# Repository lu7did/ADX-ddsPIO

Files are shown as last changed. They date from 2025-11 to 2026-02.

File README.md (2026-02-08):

# ADX-ddsPIO

A brief story of the project start with the excelent ADX Transceiver from Barb (WB2CBA) which can be found at

* Github site [link](http://www.github.com/WB2CBA/ADX).
* ADX transceiver blog [link](https://antrak.org.tr/blog/adx-arduino-digital-transceiver)

The ADX transceiver is powered by an Arduino Nano (ADX) or Arduino Uno (ADX_UNO) boards using both the 
ATMEL ATMEGA382p processor.

In order to leverage the capabilities of the transceiver with a powerful processor such as the Raspberry Pi Pico
which uses the rp2040 architecture a project called **ADX-rp2040** was started.

Then a map between the Arduino board I/O and the rp2040 I/O was made showing some differences needs to be addressed
which requires additional circuitry.

As an evolution of that project the goal to reduce the footprint of the transceiver, trying to remove the 
signal generator function (Si5351 based), this effort leads to this project.

The project aims to achiveve several (experimental) goals:

* Port the ADX firmware to the rp2040 (already done with the [ADX-rp2040](https://www.github.com/lu7did/ADX-rp2040)
* Design and develop a hardware board to support the project
* Implement a USB digital audio interface, the board can be seen as a virtual sound card.
* Implement an all Raspberry Pico based DDS generation (no Si5351 board).

Once implemented an ADX class FT8 digital transceiver can be created using
different hardware strategies.

Basic specs for this transceiver would be:

* Operate in any of the HF bands (160m to 10m), attempts to marginal use on 6m will be made.
* 2-3W output (WSPR,FT8;JS8,FT4).
* Different alternatives for receiver:
	*  DC (CD2003GP).
	*  Ssuperhet (CD20023GP)
	*  Digital (Si4732 based)
* SWR protection.
* Beacon mode (WSPR,FT8).
* ATU reset output.
* PA SWR protection (zener diode).

This project relies *heavily* on the superb work made by several authors:

* Roman (R2BDT) with his pico-WSPR-tx project (link) which in turns relies on his pico-hf-oscillator project
  [link](https://github.com/RPiks/pico-hf-oscillator)

* Hitoshi-san (JE1RAV) with his QP-7C_RP2040 project did most of the heavy lifting to use a USB for both
  digital audio and serial interface (CDC).
  [link](https://github.com/je1rav/QP-7C_RP2040).

* As said the ADX architecture has been originally developed and promoted by Barb 
  (WB2CBA) and had been spinned off by dozens of experimental implementations, most
  of the transceiver hardware is rooted on his signature original design.

* The ADX-rp2040 firmware was originally developed by me as an adaptation of the ADX Arduino firmware,
  differences with the original code were quite large so the actual final code was refactored in the process.
  [link](https://github.com/lu7did/ADX-rp2040)

* An early effort called RDX-rp2040 was originally developed as a stand alone FT8 transceiver able to
  operate without a PC, the project reach the prototype stage and stays there since. Part of the hardware
  and the si4732 utilization comes out of it,  not being an optimal implementation the board designed
  for that project can also be reused.
  [link](https://github.com/lu7did/RDX-rp2040)

* Hans Summers (G0UPL) developed the original QCX transceiver, which creates a whole
  family of high performance, yet affordable,  homebrew transceivers.

* Guido (PE1NNZ) who developed the original uSDX microcode for the Arduino which inspired
  manyfold designs, specially the uSDX class transceivers, and opened the gate for a generation
  of low cost at reasonable performance ham radio equipment.
 
With enough luck and cooperation this project might turn into a system which
includes the different components in order to be reproduced, lots of work needs
to occur for this to happen.

73 de Pedro (LU7DZ/LT7D)

# Support and issues

This is an experimental, work-in-progress, non-profit project performed as closest to the ham spirit as possible. Only spare, hobby,
time is available to move the project forward or to provide support on usage or issues.

Until further notice is provided this project is **work in progress** and not able to be reproduced directly.

If anybody has questions or issues please:
 
* Be sure you read the documentation first.
* Check on the issues list of the GitHub site, the issue might have been described there or even a workaround might exists for it.
* State it as an  English request. English isn’t even my fourth language, still I do my best to adhere to it. 
* For casual question you can use the groups.io uSDX forum and for a longer ones please open and issue at the GitHub portal of the project. 
* Express very clearly which version and level the firmware has. In most cases using the latest would solve the issue.
* Ensure the issue happens with a freshly downloaded last version of the firmware, don’t expect me to debug any modification you did.
* Describe in your own words the problem and what you did to expose it and what workarounds you attempted.
* Add the content of the monitoring terminal session with DEBUG enabled to help me understand what is going on.
* Attach any other documentation you think might help debugging the issue.

Please report ONE (1) issue per entry, and proceed as clean as possible with the debug instructions given to you to further understand or to fix the problem. 
I’ll address your issue as soon as my available time allows, not necessarily in a FIFO way.

# ADX-ddsPIO Firmware

## Architecture

The overall program architecture can be seen in the following activity graph
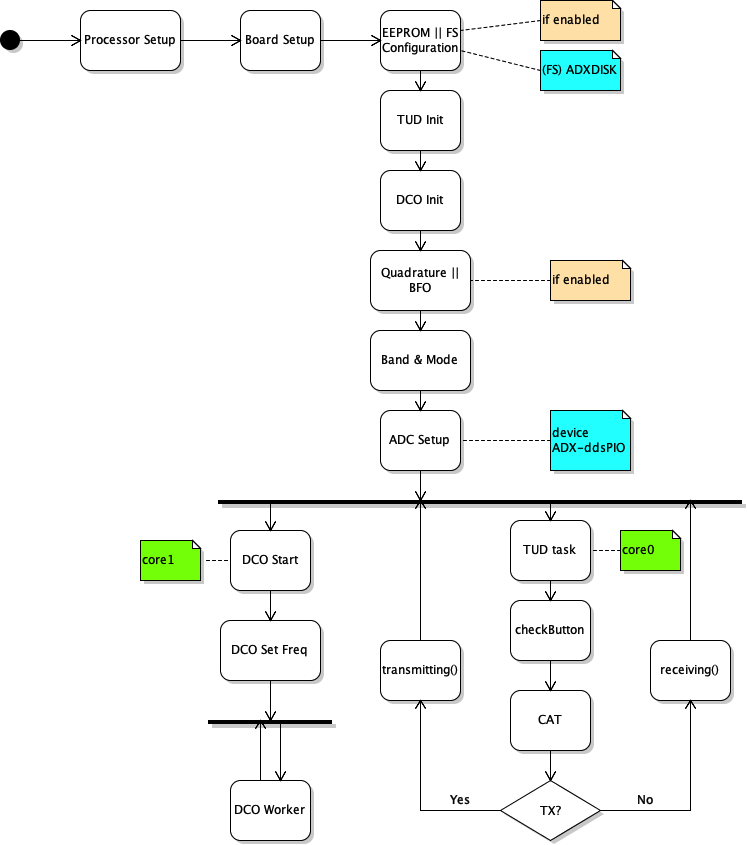
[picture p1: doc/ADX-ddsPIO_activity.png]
ADX-ddsPIO Architecture


The main Transmit-Receive cycle loop can be seen in the following activity graph
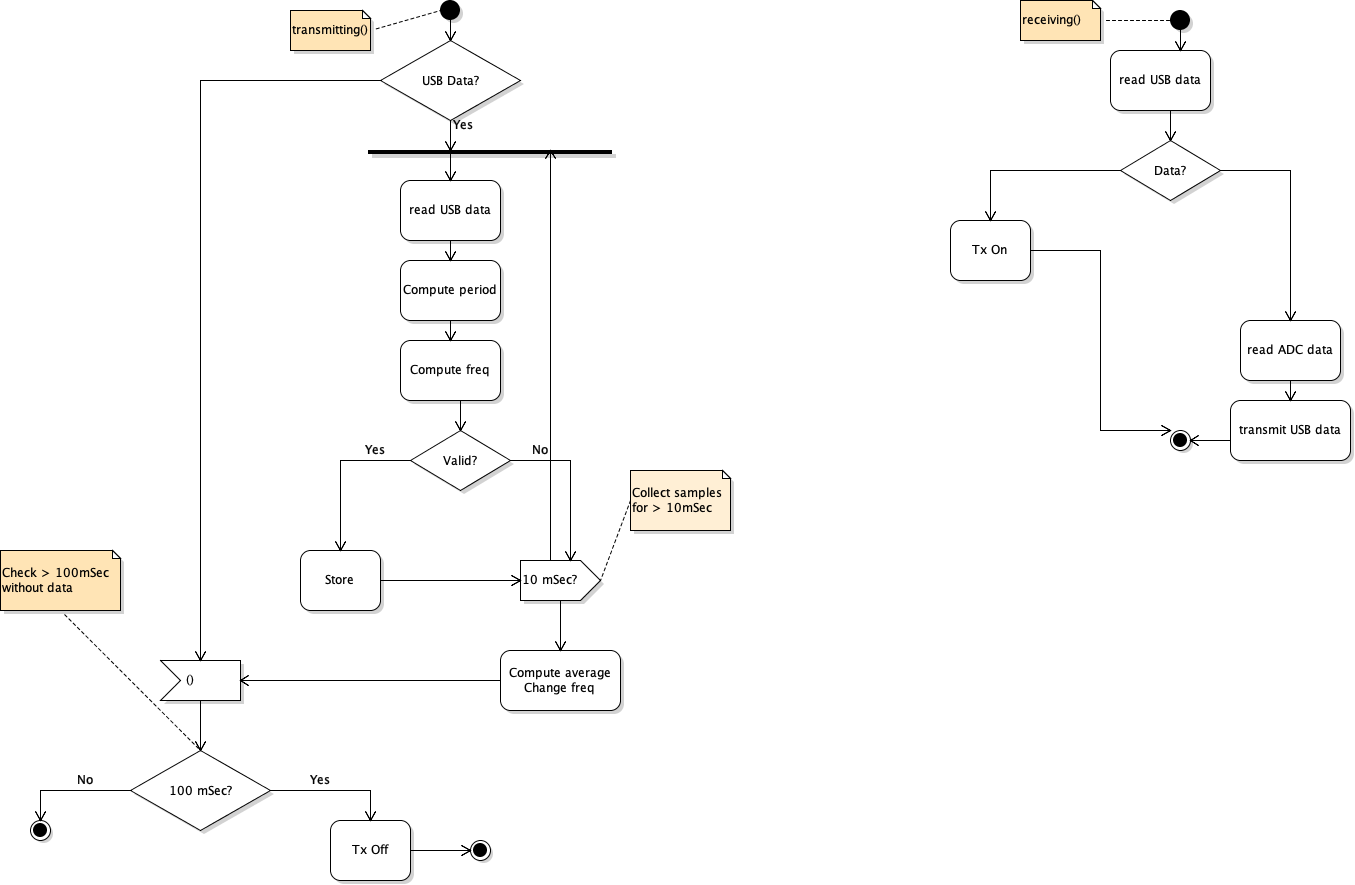
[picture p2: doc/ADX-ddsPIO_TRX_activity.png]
ADX-ddsPIO TRX cycle


## ADX-ddsPIO Firmware (Version 1.0) 

This is the first version of the firmware, the main functions implemented
are:

* Operate in any of the HF bands (160m to 10m), attempts to marginal use on 6m will be made.
* 1W RF power, DC receiver (CD2003GP based) with SWR protection.
* Management of the ADX-ddsPIO board.
* Receive and transmit digital audio data over a USB connection.
* Is able to operate with weak mode signals.

The firmware is completed at this stage and able to sustain QSO as shown in the following picture
where a contact is been made between the board (dubbed as LU2EIC) and my 20m digital FT8 station
running as LU7DZ using a direct conversion receiver setup.
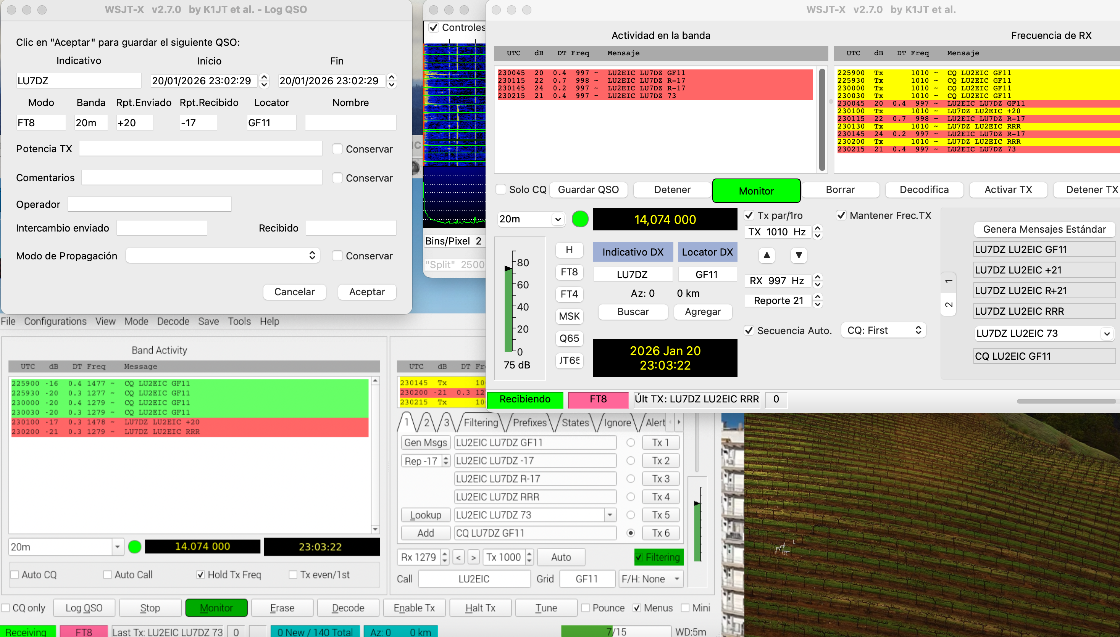
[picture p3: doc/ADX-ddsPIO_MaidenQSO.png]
ADX-ddsPIO Maiden QSO

Although the RF setup is close to trivial, just few meters distance, the activity has been held
"over the air" and shows the firmware is able to properly encode and decode signals both at the
audio and RF levels. My 20m station is composed of a QDX transceiver being run by a Raspberry Pi
controller running a modified version of WSJT-Z whilst the testbed for the ADX-ddsPIO is my
Mac running the MacOS version of WSJTX. For all practical purposes this is considered the 
"maiden QSO" of the board and all goals for this level can be called as completed.

## ADX-ddsPIO Firmware (Version 1.1)

Features

* Permanent settings (EEPROM emulation).
* CAT control (TS2000 emulation).

## ADX-ddsPIO Firmware (Version 1.2)

* Superhet ADX-S support.
* Implementation of a BFO (465 KHz) local oscillator.

## ADX-ddsPIO Firmware (Version 1.3)

* Quadrature based receiver (SDR) support (quadrature clock available)

## ADX-ddsPIO Firmware (Version 2.0)

* Si4732 based receiver chipset support
* USB (MSC) drive filesystem implementation to store external configuration (CONFIG.SYS) 

The firmware is completed at this stage and able to sustain QSO as shown in the following picture
where a contact is been made between the board (dubbed as LU2EIC) and my 20m digital FT8 station
running as LU7DZ using the Si4732 chip as a receiver.
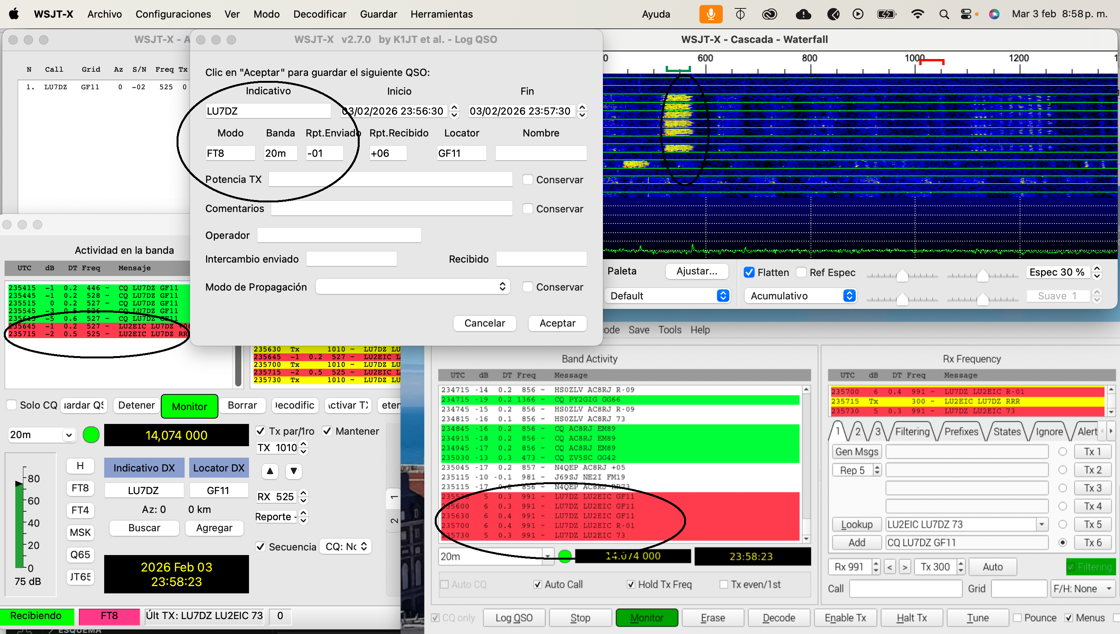
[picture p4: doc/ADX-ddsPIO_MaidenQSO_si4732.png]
ADX-ddsPIO Maiden QSO


## Build environment

The development environment used is Visual Studio code using the standard Raspberry Pi Pico C/C++ SDK.

Please follow the official documentation of both to install and configure the functionality.

## Flashing the firmware

The firmware could be flashed directly to the Raspberry Pi Pico (rp2040) processor on the
board following the conventional BOOTSEL method.

The file to flash is *./src/build/ADX-ddsPIO.uf2* .

# Hardware

I started the porting of the firmware assuming an ADX transceiver board, no more but no less features, but being powered
by a Raspberry Pico board; the porting of the software was a great deal of a learning curve not only for the rp2040
architecture being different from the ATMEGA382p and being more powerful, but also a substantially different build chain
which in some cases is implementing partially some features. For migration purposed the Raspberry Pi Pico board was used.

## Board support

At his point the Raspberry Pi Pico (standard) and the RP2040 Zero boards are *supported*.

The Raspberry Pi Pico W (wireless) is **not supported**.

## Circuit Design Si4732 based Receiver (version 2.x)

This circuit is largely based on the former RDX_rp2040 project design and it's compatible
with that board design with just minor mods.
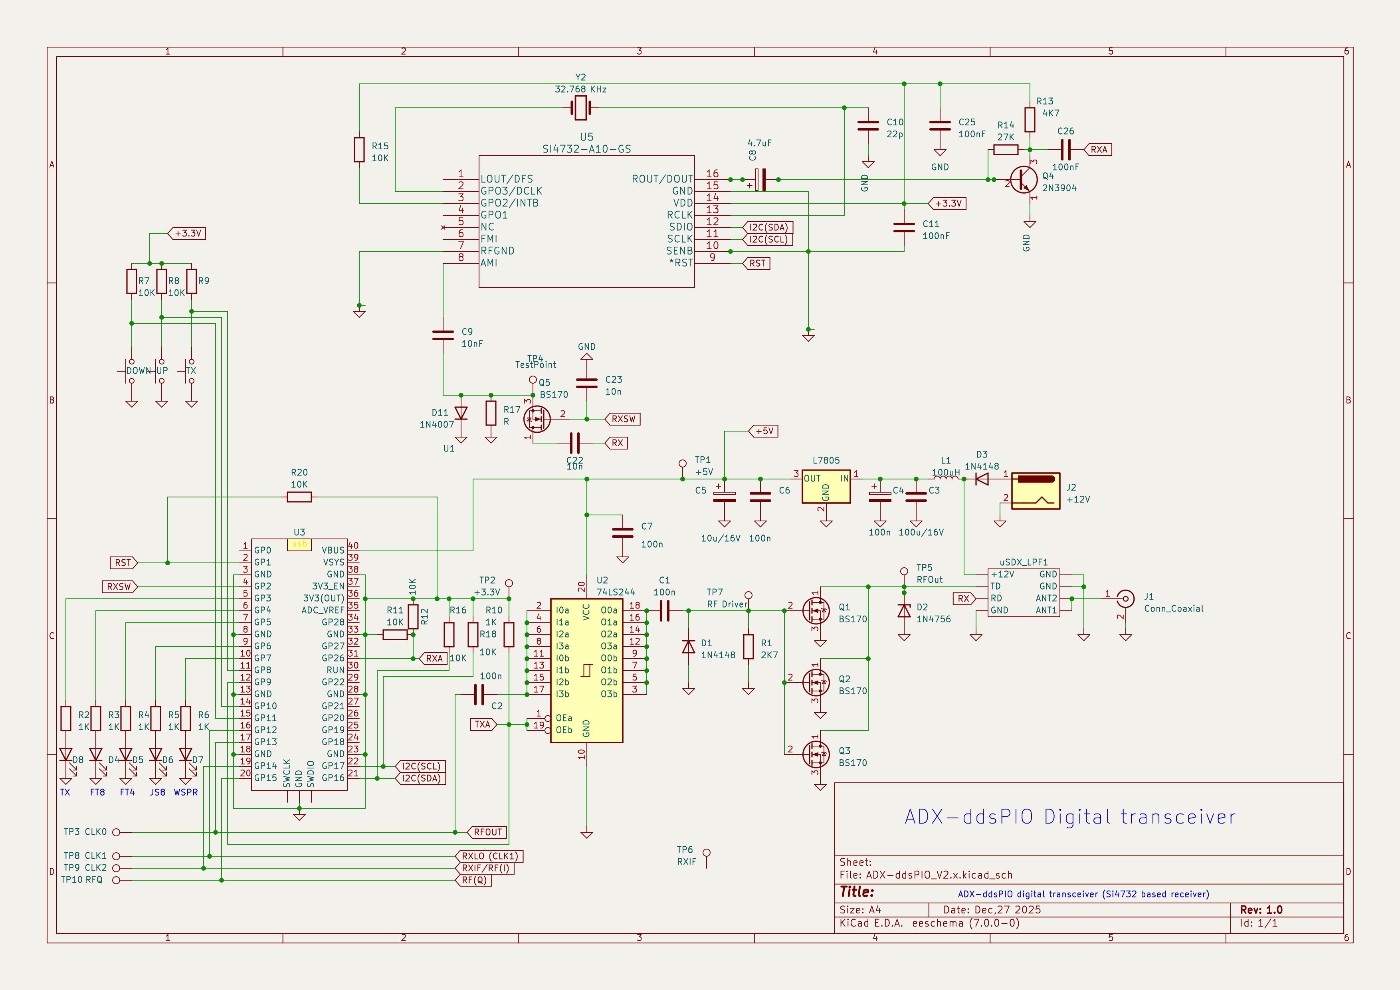
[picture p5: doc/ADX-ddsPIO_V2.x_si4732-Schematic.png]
Transceiver Circuit (Version 2.x)


The main differences with the verion 1.x:

* The receiver configuration has been changed to use the Si4732 receiver chipset.

A new, fresh, board design will eventually be made, however the development is supported with 
a prototype based on a modified RDX_rp2040 board.

### Modifications to adapt RDX board to ADX-ddsPIO

Modifications could be made to the RDX board to operate with firmware level 2.x or up
main advantage at this point is the availability of a PCB design which allows the usage
of SMD components easily.

The required mods for the RDX board to work with the ADX-ddsPIO firmware are:

* Cut the PCB wire PICO ADC0 (GPIO26) to R10/R11/C10.
* Run a wire  from R10/R11/C10 to PICO ADC2 (GPIO28).
* Run 2 pullup 10K resistors from PICO GPIO16 to +3.3V and GPIO17 to +3.3V.
* Do not use a Si5351 breakout board
* Run a wire from GPIO13 to the CLK0 pin of the Si5351 place.
* Run a 10K pullup resistor from Si4732 pin 3 (INTB) to +3.3V.
* If running with an external +12V cc supply remove jumper J7.
  
```
Work in progress
```

## Circuit Design Superhet Receiver (version 1.x)

This circuit is largely based on the ADX transceiver modification made by Hitoshi Kawaji (JE1RAV) and
marketed as a kit form by Adam Rong (BD6CR) at CRKits.com ([link](http://crkits.com/) ).
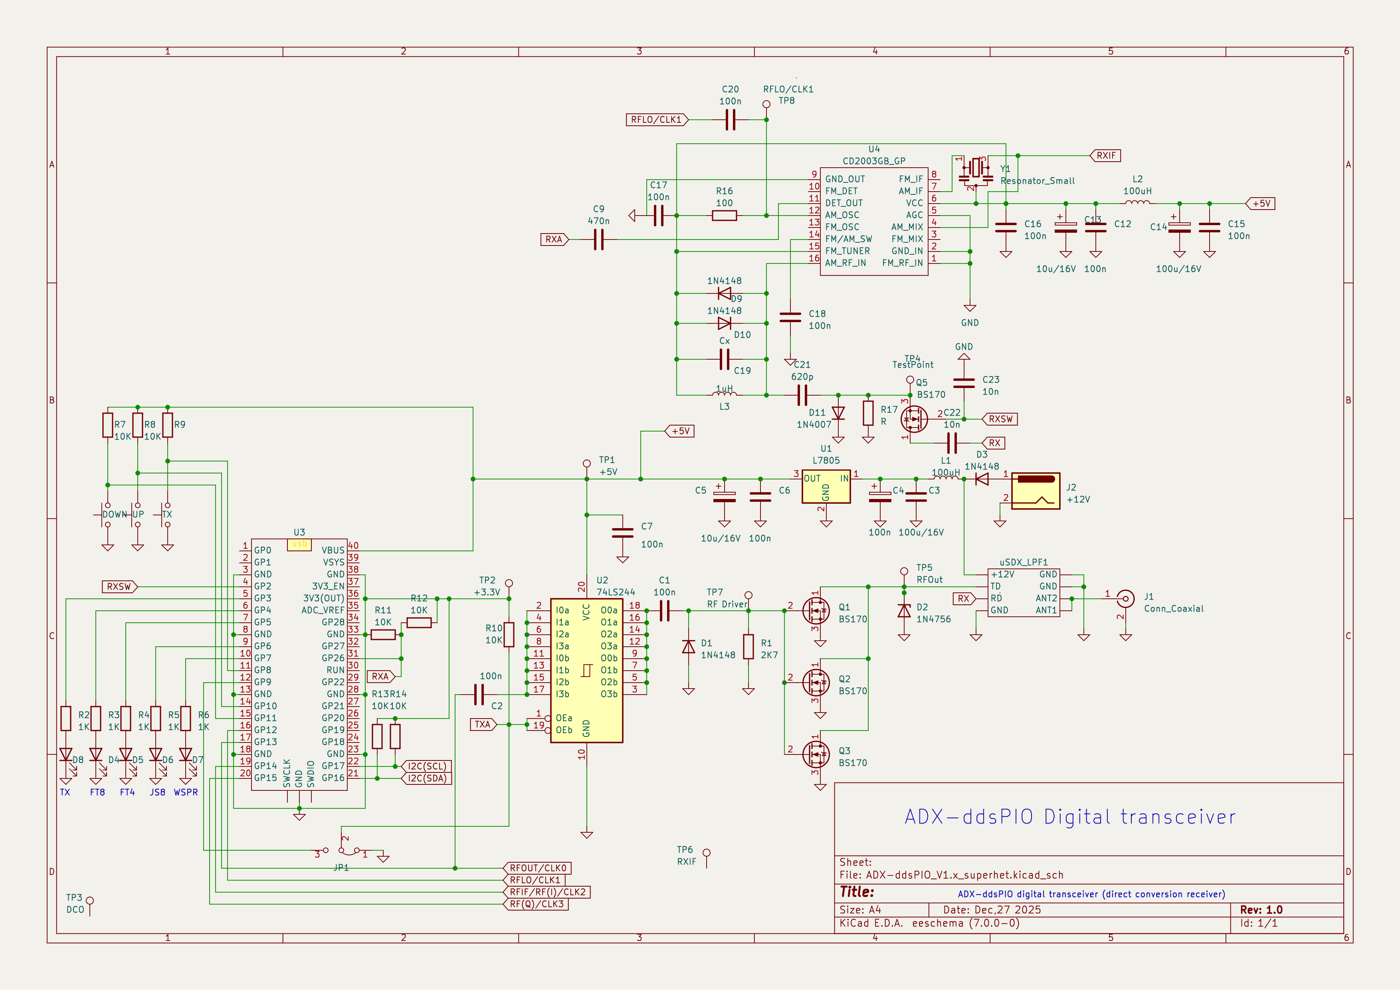
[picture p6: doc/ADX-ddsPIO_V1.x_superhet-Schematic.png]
Transceiver Circuit (Version 1.x)


The main differences with the verion 0.x:

* The receiver configuration has been changed to a superhet.

## Circuit Design Direct Conversion Receiver (version 1.x)

This circuit is largely based on the original ADX transceiver [link](https://github.com/WB2CBA/ADX) by Barb ([WB2CBA](https://www.qrz.com/db/WB2CBA))
modified for the rp2040 processor at the ADX-rp2040 project.
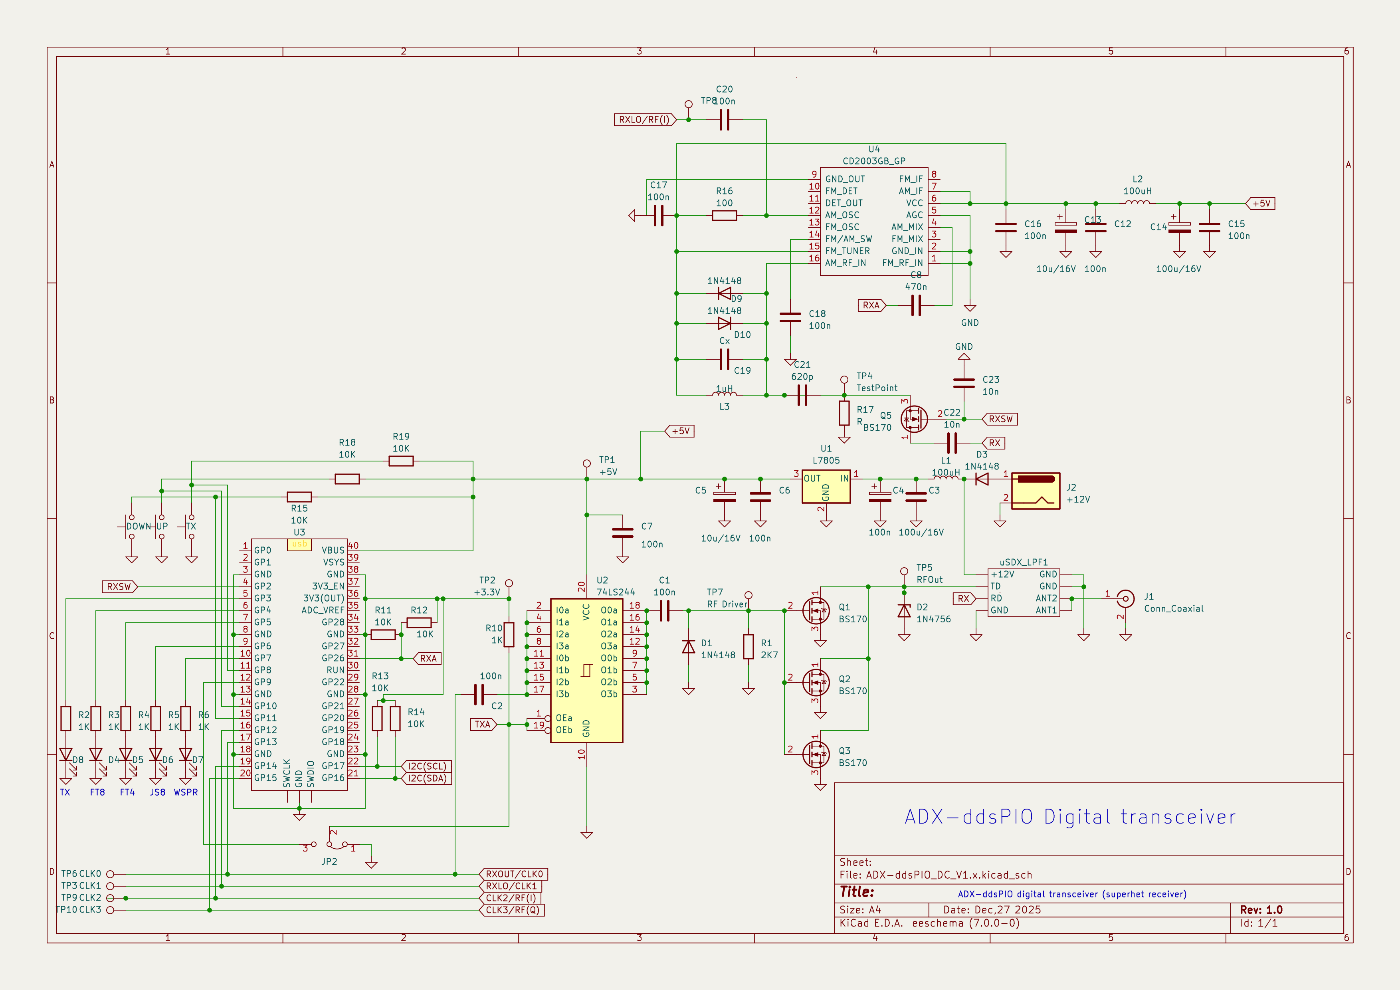
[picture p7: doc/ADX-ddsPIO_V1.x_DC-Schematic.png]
Transceiver Circuit (Version 1.x) Direct Conversion


The main differences with the original ADX circuit are:

* Si5351 module no longer present.
* Analog audio circuit has been removed as the audio information is received digitally thru USB.

## Pinout assignment

The pinout assignment for this version is shown in the following table:

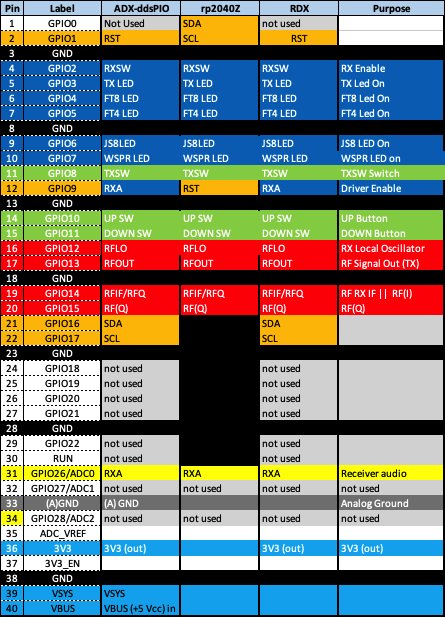
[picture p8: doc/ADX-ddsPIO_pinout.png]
Raspberry Pi Pico pinout assignment


## File System (FS) architecture

A simple FAT-16 (MS-DOS) filesystem is implemented using a USB (MSC) interface, although the space is very
limited it can be used to store any file on it. When plugged the name of the inserted device will be 
*ADXDISK*.

The firmware uses just one of them called *CONFIG.SYS* which stores a master configuration for the board, if
the board is initiated with the file system empty (first boot) a CONFIG.SYS file with the default configuration
will be written. In order to reset the board content (and the flash memory containing the configuration) 
the power up needs to be made while keep pressing the TX switch (the default LED will flash quickly), upon
release the file content will be erased and the CONFIG.SYS file regenerated with the default configuration
values.

This is a sample of a CONFIG.SYS file managed by the system

```
{
"ID" : 1,
"mode" : 4,
"slot" : 3,
"volume" : 60,
"bandwidth" : 1,
"frqFT8" : 14074000
"frqbfo" : 446400
}
```

Because of it's simplicity the filesystem will not support directories.

The logic is as follows:

* The main default configuration (sort of a factory default) is stored as constants defined at build time.
* If EEPROM is enabled
	* the factory defaults are stored in EEPROM to make them persistent.
* If FS is enabled 
	* will override the EEPROM directive and take configuration from the CONFIG.SYS file.
	* If the CONFIG.SYS file is erased the next boot the default configuration will be taken and a new CONFIG.SYS file created.
	* Any change in the CONFIG.SYS file will be made permanent by properly *EJECT* the USB device in the host computer.
* Either the content of the EEPROM or the FS will override the factory defaults.

### Use case EEPROM vs File System

Both methods are sort of redundant and will not operate at the same time, whether the configuration is stored in EEPROM,
File system or not stored is configured at build tiime by means of the configuration options choosen.

* (not EEPROM && not FS) the configuration will not be persistent across reboots, any change made during operation
  will be lost once the board is powered down.
* (EEPROM && not FS) the configuration will be persistent across reboots, it will start with the defaults but any change
  will be stored in EEPROM and recovered in the next boot.
* (not EEPROM && FS) the configuration will be taken from the CONFIG.SYS file and override the board defaults, however
  any change made won't be saved into the CONFIG.SYS file and therefore will be lost when the board is powered down.
  However, changes made externally on the CONFIG.SYS file will be taken on the next boot and on. All changes made 
  externally on the CONFIG.SYS file will require the media to be ejected to become permanent.
* (EEPROM && FS) if this configuration is detected FS will be taken and EEPROM discarded at bootup.

### Configuration clean up

The board defaults can be changed and made effective by changing the configuration options and recompiling the firmware.

* (not EEPROM && not FS) no configuration to clean up, powering down and up the board will restore the defaults.
* (EEPROM and not FS) powering up the board with the TX switch pressed will reset the EEPROM to the board defaults.
* (FS and not EEPROM) erasing the CONFIG.SYS file (or editing it) and ejecting the USB media will clean up the configuration.
* (FS and EEPROM) FS will prevail.

## Master configuration

The configuration at build time is set by a number of #define clauses
```
#define  DEBUG      1     //Will enable the traces to be sent thru Serial Monitor, also the boot will stop until it is enabled
#define  EEPROM     1     //Enable EEPROM simulation in flash memory
#define  SUPERHET   1     //Enable the creation of a 455 KHz BFO signal
#define  QUAD       1     //Enable the creation of a Quadrature oscilator signal (SDR operation)
#define  SI4732     1     //Enable the support for the Si4732 chip
#define  WAITSERIAL 1     //Enable waiting for the Serial Monitor to be up to continue loading
#define  FS         1     //Enable file system FAT-16
#define  RTC        1     //Enable real time clock and time sync (partially implemented)
#define  CAT        1     //Enable CAT support

```

Some of the features conflicts among them so there is a dependency filter setup as follows that should not be modified.

```
#ifdef FS                        //EEPROM emulation or USB file system, FS prevails
#undef EEPROM
#endif //FS

#ifdef SI4732                    //If Si4732 chipset enabled it's the dominant receiver
#undef SUPERHET
#undef QUAD
#undef RTC
#endif //SI4732

#ifdef CAT                      //If CAT enabled USB can not be used to debug
#undef DEBUG
#undef RTC
#endif //CAT  

#ifdef QUAD                     //If Quadrature oscillator activated all other clocks disabled
#undef SUPERHET
#undef SI4732
#endif //QUAD 

#ifndef DEBUG                   //If not in DEBUG mode will not wait for Serial Monitor to activate
#undef WAITSERIAL
#undef RTC
#endif //!DEBUG

```

## Clock Architecture

The board supports and the firmware implements several clock models which can be configured
for different board setups.

* Dual clock   (DC Receiver).
* Dual clock + IF (Superheterodyne)
* Quadrature (SDR)

### Dual clock 

In this setup the clock is produced simultaneously from GPIO13 and GPIO14, both signals
are identical, both in receiving or transmitting mode. It's intended to make the circuit
simpler. Actual operation of the board will require other signals such as RXSW and TXA
to properly operate to be controlled by the firmware. This clock also uses a derivative
of the VCO done by Roman (R2BDT) modified to replicate the output of the PIO on pins
GPIO13 and GPIO14 simultaneously.

### Dual clock + IF

Then the board operates with a superheterodyne receptor configuration the receiver process
requires two clocks, the main one to operate the down-converter mixer from the HF frequency
to an intermediate frequency and other as the intermediate frequency oscillator frequency.

The down-converter local oscillator (RFLO) can be either one of the clocks despicted above.

The intermediate frequency clock (RFIF) is a special clock, it's lower in frequency and 
therefore it's easier to implement on a processor with limited resources. Also it's a 
fixed frequency as it doesn't vary with the operation.

Unfortunately attempts to extend the VCO concept to simultaneously create a different
clock at a different frequency prooved to be beyond the limits of the processor; the VCO
uses for itself a whole core (*core1*) in **blocking mode** so no other task can be interleaved
without causing jitter, spurious outputs or frequency drift or all three together. At the same
time the other core (*core0*) it's actually devoted to provide all the other tasks of the
board such as USB Audio, USB CDC (serial), board management, signaling, timers, etc.

A different approach is then intended. the rp2040 processor has several specialized processors
called PIO (Programmable Input/Output) which are a limited memory, limited instruction set (RISC)
processors but completely independent from the main processor. Each processor executes their 
program as part of a *state machine* (SM) which dictates which instruction is executed
at each clock cycle.  They are programmed in a special 
Assembler language (*PioASM*) and are extremely useful to perform I/O without tying up the
processor or forcing the handling of interrupts on the main cores.  

To generate a clock for the intermediate frquency a PIO is assigned with that purpose
the state machine (SM) of the selected PIO runs at the frequency $f_{sm}$.
If the PIO program makes a toggle of the signal every cycle then the output frequency ($f_{out}$) would be:

$f_{out}=\frac{f_{sm}}{2}$

For an estimated 465 KHz frequency for the IF of the receiver then

$f_{sm}= 2*465 KHz = 930 KHz$

The clock used by the PIO is derived from the system clock ($clk_{sys}$) thru a fractional divisor,
as the board is being clocked at 270 MHz then

$clk_{div} = \frac{clk_{sys}}{f_{sm}} = 270e6 / 930e3 \approx{290.32266}$

However, the actual divisor used by the rp2040 has a resolution of 1/256, so in this case:

$f_{out} = \frac{f_{clk}}{2 \cdot div}$

where:

$div = INT + \frac{FRAC}{256}$

The ideal divisor would be 

$div_{ideal} = \frac{f_{clk}}{2 \cdot f_{obj}}$

$div_{ideal} = \frac{270\,000\,000}{2 \cdot 465\,000} = 290.3236$

As the hardware allows only for steps of 

$\Delta div = \frac{1}{256} \approx 0.00390625$

A split is made:

$INT = 290$

$FRAC = round(0.3236 \cdot 256) = 82$

A split needs to be made

$div_{real} = 290 + \frac{82}{256} = 290.3203$

And the real frequency obtained would be

$f_{real} = \frac{270\,000\,000}{2 \cdot 290.3203}$

$f_{real} \approx 465003.6529 \ \text{Hz}$

The quantization introduces then an error of 

$\Delta f = f_{real} - f_{obj}$

$\Delta f \approx -3.6529 \ \text{Hz}$

Being the relative error 

$\varepsilon = \frac{\Delta f}{f_{obj}}$
$\approx 7.85 \times 10^{-6}$

$\varepsilon \approx 8 \ \text{ppm}$

This error factor is accounting **only** for the fractional divisor error of the PIO. Other sources
of error needs to be considered such as
* Board crystal tolerances.
* PLL error.
* Thermal drift.
* Fractional divider internal jitter.

However, the level of error obtained is a good compromise between performance, cost and simplicity.

The waveform obtained at GPIO15 is as follows for a nominal $f_{BFO}=446400 \text{Hz}$

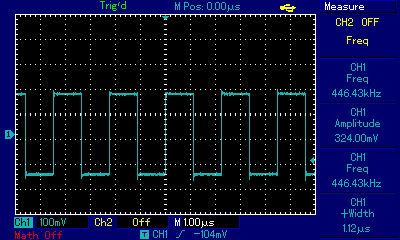
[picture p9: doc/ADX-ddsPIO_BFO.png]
ADX-ddsPIO BFO
  

The outputs at GPIO13 and GPIO14 would be a clock at the operating frequency whilst the output
at GPIO15 (when option **#define SUPERHET 1** is set) would be a fixed clock of the established
frequency (normally in the 450 KHz range) as shown in the following picture.

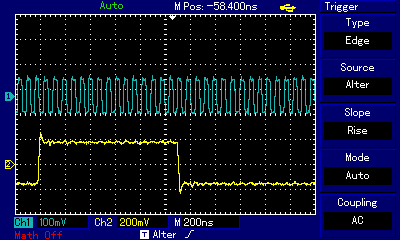
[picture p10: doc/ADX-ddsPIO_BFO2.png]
ADX-ddsPIO BFO
  

```
This option is activated with the compilation directive #define SUPERHET 1
This option is deactivated with the compilation directive #define QUAD 1
```

### Quadrature clock

If a Software Defined Radio (SDR) receiver is needed the board has to provide two specific signals
called by convention clock *I* and clock *Q* which are of the same frequency but whose phases are
90 $\textdegree$ appart or $\frac{\pi}{2}$ 

Again, trying to obtain such signal using the VCO technology it's quite difficult with the 
resources available, an approach to create them using again a PIO processor with that purpose
is made.

The result is a *digital quadrature frequency synth (I/Q)* and it's architecture and logic
follows.

```
This option is activated with the compilation directive #define QUAD 1
This option is deactivated with the compilation directive #define SI4732 1
```
 
### Si4732 receiver

When the board uses a Si4732 based receiver the clock generated by the rp2040 is only needed
for transmission as the receiver generates it's own clock.

For simplicity the transmission clock (CLK0 and CLK1) are turned off while in reception and
turned on while on transmission.

```
This option is activated with the compilation directive #define SI4732 1
This option override all other configuration options
```

#### Architecture

The architecture combines:

* Dynamic reconfiguration of the board clock (PLL_SYS).
* Generate quadrature signals using a 4-state PIO logic.
* Manipulate the fractional divisor (Q8.8) of the PIO state machine.
* Perform a frequency optimization of the error.

The system achieves typical errors in the 0-50 Hz range over the HF spectrum, being the receiver clock 
and being stable on that error this is quite compatible with digital modes such as FT8, the only effect
would be than the *"nominal"* frequency of the incoming signal with be shifted up or down by the error
(few Hz) in a stable way.

Main components are

* PLL_SYS (RP2040).
* Main boar clock (clk_sys).
* Configurable divider:
	* refdiv
	* fbdiv
	* postdiv1
	* postdiv2
* PIO (Programmable I/O)

The PIO executes a cyclic firmware with 4 states which generates the quadrature
signal over 2 output pins

	00 → 01 → 11 → 10 → repeat

Each instruction is executed in one clock cycle of the state machine, therefore
manipulating the clock of that PIO state machine using a fractional divider the
output frequency can be manipulated:

$D=d_{int}+\frac{d_{frac}}{256}$

Selecting two consecutive pins the signals *I* and *Q* can be extracted from each.

The synthesis math model follows

Each instruction of the PIO is executed in:
$T_{inst}=\frac{D}{f_{clk_sys}}$ 

In order to complete a full period all 4 instructions needs to be executed

$T_{out} = 4 \times T_{inst}  = \frac{4D}{f_{clk_sys}}$ 

Therefore the output frequency ($f_{out}$) will be:
$f_{out}=\frac{f_{clk_sys}}{4D}$

Using
$N=256D$

Results

$f_{out}=\frac{f_{clk_sys} \times 64}{N}$

Which is the master equation of the system operation

When a target frequency ($f_{req}$) is needed as a goal
and the system is running with a clock ($f_{clk}$) the
problem is to define a divider

$N^*=\frac {f_{clk} \times 64}{f_{req}}$ 

But the hardware is limited to 
$N \in Z,1 \le 65535$

Therefore not all values of $N$ are feasible but
$N=Round({N^*})$

And the true frequency resulting would be

$f_{out} (N)=\frac{f_clk \times 64}{N}$

and the error 
$ε=f_{out} (N)-f_{req}$

When computed over the HF range the error could become quite large, from
several Hz in the lower bands to close to 30 KHz in the higher bands, this
is not acceptable.

To minimize the error two factors needs to be defined, the divisor but also the system clock
in a way that an exploration of the  discrete space of solutions 

* $refdiv\in[1,16]$
* $fbdiv\in[16,320]$
* $postdiv1\in[1,7]$
* $postdiv2\in[1,postdiv]$

With:
* $f_{ref}=\frac{f_{xosc}}{refdiv}$
* $f_{vco}=\frac{f_ref}{fbdiv}$
* $f_{clk}=\frac{f_{vco}}{postdiv1 \times postdiv2}$

Subject to the following constraints:

* $400 \text{MHz} \le f_{vco} \le 1600 \text{MHz}$
* $f_{clk} \le f_{max_sys}$

A minimization optimization problem can then be solved with the 
following border conditions

For each valid PLL configuration a computation is made
$N^*=\frac {f_{clk} \times 64}{f_{req}}$ 

All candidates are evaluated
$[N-1,N,N+1]$

For each 
$f_{out} (N)=\frac {f_{clk} \times 64}{N}$

Searching for the minimum of 
$\left \lvert \epsilon \right \rvert = \left \lvert {f_{out}-f_{req}} \right \rvert$

Selecting as a result the value with the minimum absolute 
error 
$[f_{clk},N]$

This is a discrete search with a double optimization:
* PLL quantization.
* Divider (Q8.8) quantization

The theoretical error limit is  
$\left \lvert \Delta N \right \rvert \le 0.5$

taking derivatives 
$\frac {df}{dN}=- \frac{f_{clk} \times 64}{N^2}$

Being the approximate máximum error value:
$\left \lvert \epsilon_{max} \right \rvert \approx \frac{f_{clk} \times 64}{2 \times N^2}$

Since
$N \approx \frac{f_{clk} \times 64}{f_{req}}$ 

results
$\left \lvert {\epsilon}_{max} \right \rvert \approx \frac{f_{req}^2}{2 \times f_{clk} \times 64}$

As a consequence 

* Error is reduced when $clk_{sys}$ increases.
* Error grow quadratically with the $f_{req}$
* The divisor cuantization controls the residual error.

A typical expected result would be
|Band|Freq|clk_sys|Error|
| --- | --- | --- | --- |
| 80 m |  3 573 000 | 167 428 571 | 0 Hz |
| 40 m |  7 074 000 | 233 000 000 |  ±3 Hz |
| 20 m | 14 074 000 | 268 285 602 |  ±2 Hz |
| 15 m | 21 074 000 | 178 800 000 | ±30 Hz |
| 10 m | 28 074 000 | 261 000 000 | ±50 Hz |

The output of this clock is implemented to be obtained at pins GPIO14 (I) and GPIO15 (Q).

The resulting waveform is similar to the following example (for 3.5 MHz)
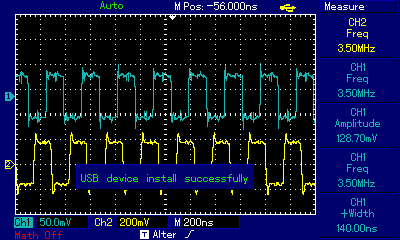
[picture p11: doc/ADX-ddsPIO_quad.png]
ADX-ddsPIO Quadrature frequency synthetizer
  

```
This clock is activated by the directive #define QUAD 1
```

## Test resources

The following test resources has been built

### ADX-ddsPIO mockup

In order to develop the first stages of the firmware a reduced mockup has been used
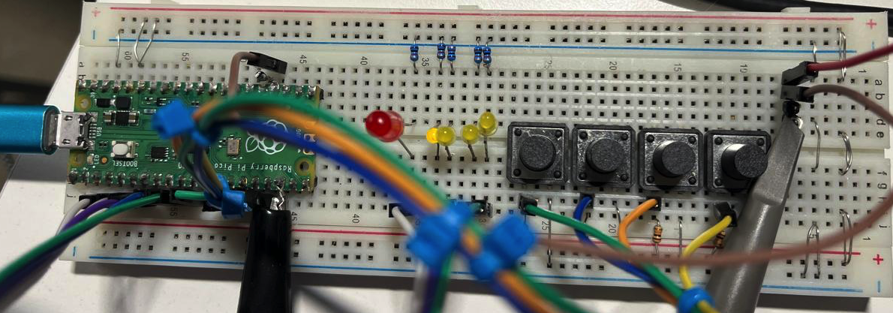
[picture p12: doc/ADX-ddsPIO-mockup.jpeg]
ADX-ddsPIO-mockup

This reduced scope board contains just the processor and the push buttons. A small
RF probe is feed into a wire for local "on the air" tests.

### ADX-ddsPIO prototype

To continue developing the board a first cut prototype board is built as shown in the
figure
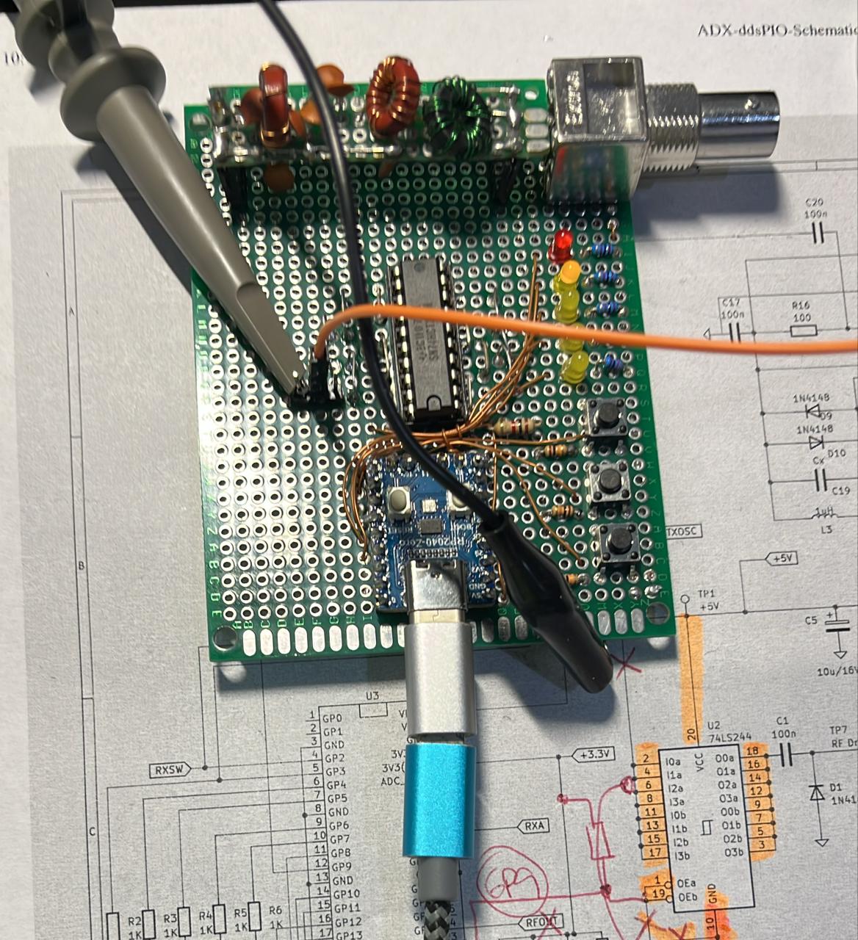
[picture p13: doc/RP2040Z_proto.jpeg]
ADX-ddsPIO Prototype

The building technique is to make connection with hand made wiring, the Raspberry Pi Pico
board has been replaced with a rp2040 Zero board which is essentially the same but with
a much smaller footprint. The main disadvantage of this board is that not all the GPIO
pins are expossed, but still as the ADX-ddsPIO board uses just few GPIO lines it's quite
adequate.
```
Just the transmitting part sans finals has been made as yet as the measurements associated
with the firmware development requires large periods with the board in TX mode and there
is no point on running finals for that.
``` 
### ADX-ddsPIO extended prototype

To continue the development of the firmware adding the reception sub-systems an extended
prototype including a receiver has been built.
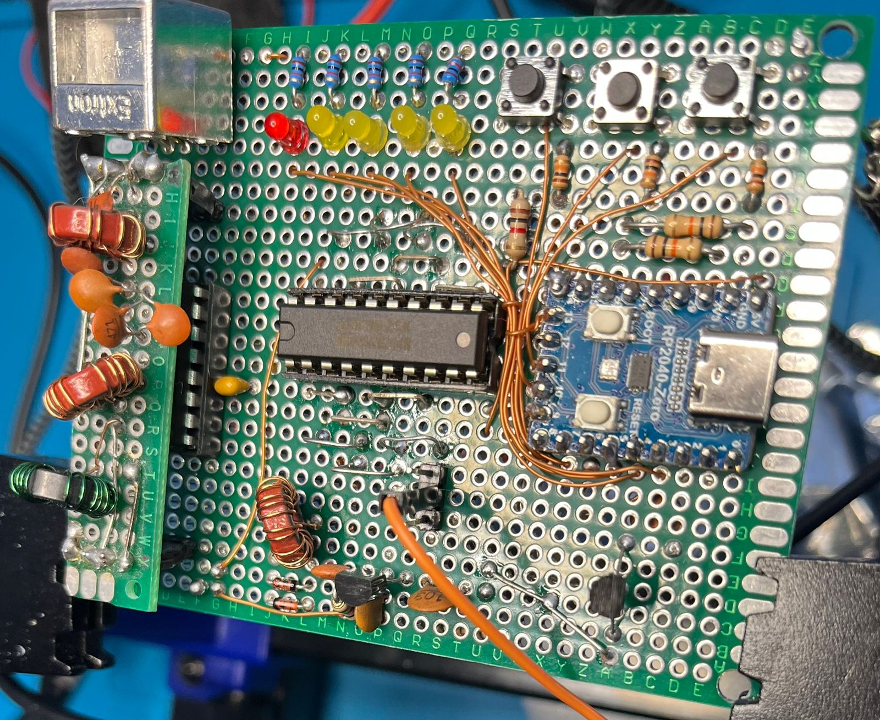
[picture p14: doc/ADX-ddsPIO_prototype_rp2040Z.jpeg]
ADX-ddsPIO-prototype

This prototype contains the processor, the RF driver and the simple *CD2003GP* based
DC receiver. The processor board used is the breakboard rp2040Z which provides the
same funcionality than the Raspberry Pi Pico with a reduced availability of GPIO and
other pins but with a much smaller board footprint.
A small RF probe is feed into a wire for local "on the air tests".

### RDX-rp2040 modified prototype

To continue the development of the firmware adding the Si4732 based receptor a modified
version of a board from the RDX-rp2040 project has been used with small mods in order
to adapt for the differences

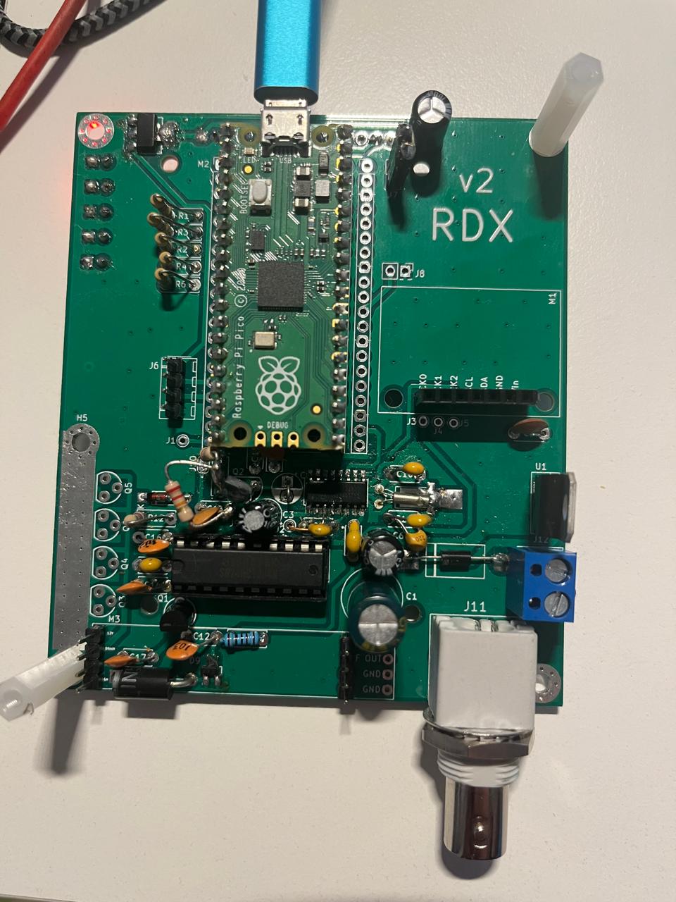
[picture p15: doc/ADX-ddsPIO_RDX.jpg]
ADX-ddsPIO RDX


Mods follows:

```
Work in progress
```

### testDDS utility

This utility is a reduced firmware implementing the DDS using a fixed frequency given
by the GEN_FRQ_HZ parameter in the ddsTest.h file. It's main purpose is to explore
the concept and the initial measurements using the Raspberry Pi Pico as an RF generator.
Also to integrate the code originally on the *pico-hf-oscillator* package on this
project.

```
This code is a crude porting of the test.c program from the pico-hf-oscillator package
```

### testFT8 utility

This utility has been created as a reduced scope test bed for the board and some of the
DDS functions applied to the generation of FT8 signals.

* When boot if the SYNC button **IS KEPT** pressed the firmware waits and upon release enters the FT8 test mode, it's 
  important the SYNC button is released as close to the top of the minute (sec=0) of
  any minute. In this way the internal clock is set at a random date time but the 
  second is synchronized. At the start of each minute a fixed message is sent using
  FT8. The message to be sent can be changed by modifying the *message* memory area, the 
  base frequency (and band) can be set changing the *GEN_FRQ_HZ* (in Hz) parameter and the
  shift within the FT8 sub-band changing the *FT8_BASE_HZ* (in HZ) parameter.
  While activated in this mode the TX can be turned on by pressing the **TX** button.

The following figure shows how WSJT-X receives the local message
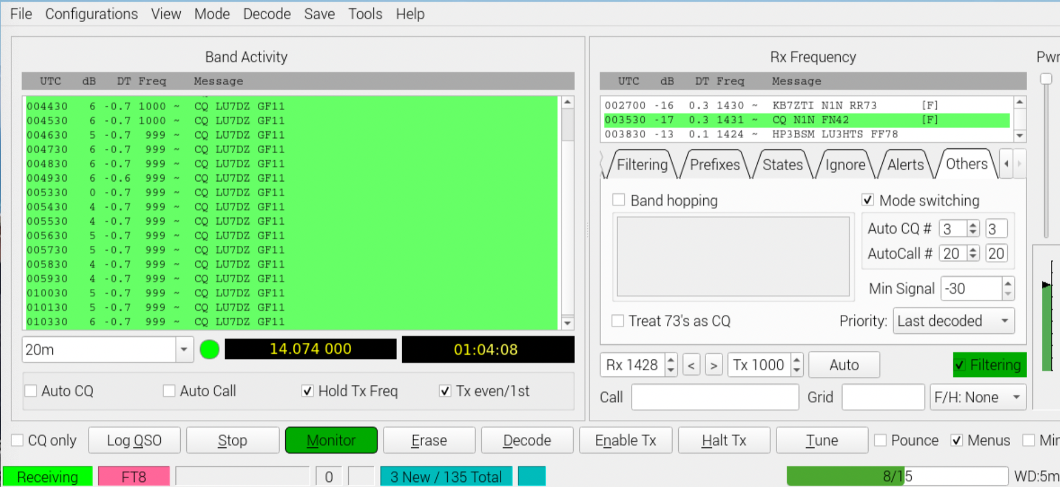
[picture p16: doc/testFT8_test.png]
testFT8 Test


```
When using a wire out of the GPIO 18 pin to transmit "on the air" signals the spectrum
is *extremely* dirty. Do not put this signal into any meaningful antenna and use it
only by short evaluation tests.
```

## testADX utility

This utility continues the integration of the firmware system incorporating the 
features of the ADX board such as UP/DOWN buttons, TX button and the four mode LED
(FT8,FT4,JS8 and WSPR) as well as the TX LED.
The board continuously generates an RF signal, when in RX mode (RXSW high) the output
is connected with the receiver (RXOSC) whilst when in TX mode (RXSW low, TX high) the
output is connected to the driver section.
If properly synchronized (see testFT8) upon start the firmware sends a message at the
top of every minute using the defined frequency and mode.

```
When using a wire out of the GPIO 18 pin to transmit "on the air" signals the spectrum
is *extremely* dirty. Do not put this signal into any meaningful antenna and use it
only by short evaluation tests.
```

## testUSB2 utility

This utility is a strip down version of QP-7C_rp2040_cat with both the USB audio and
serial data enabled.
The USB audio stream is read and the frequency computed averaging the results every
10 mSecs, the result is displayed thru the serial monitor (while the USB audio 
continue working) showing both the frequency counting algorithm and the operation 
of the USB serial monitor.

```
The test configuration needs the followigh steps:

* Compile and load the firmware.
* Open the serial monitor pointing to the */dev/tty.usbmodem00000xx - TinyUSB* device
* Start the supervision of the serial monitor channel.
* Start WSJTX and configure in the AUDIO tab
	* Input: ADX-ddsPIO
	* Output: ADX-ddsPIO
* Start the TX Tone, the serial monitor should mark the tone frequency as set in WSJTX.
* Start the FT8 TX, the serial monitor will show the different tones sent.

The counting algorithm has +/- 1  Hz accuracy, this can be improved later choosing
the averaging time, but should be enough to properly decode the frequency and
change it accordingly.
```

## testUSB3

This is a hack to integrate the Audio USB version (testUSB2) with the DCO version (testADX)
into a single firmware, crude at best, but mainly intended to explore and resolver the
(really many) hardware conflicts and library incompatibilities.

For most part it's a functional transmitter as shown in the following picture where a local
copy of WJST-X running on a Mac (test station) is evaluated in my main WSJT-X station, it can
be seen the transmission and the decoding of it.

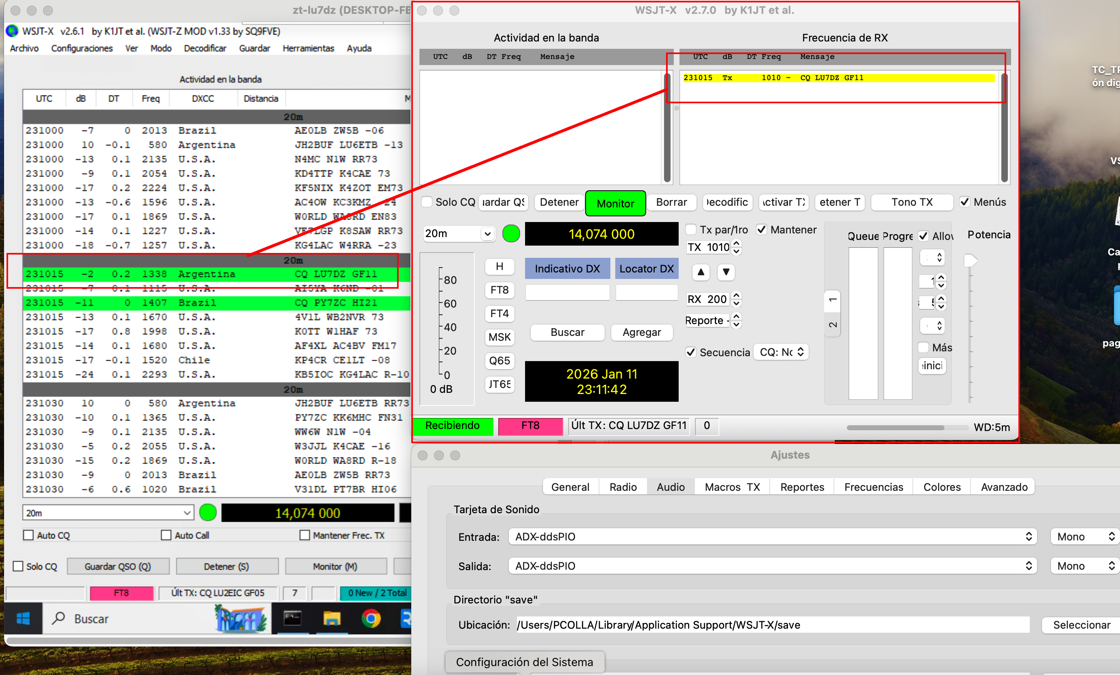
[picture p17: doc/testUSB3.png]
testUSB3 Test


At the bottom of the image the WSJT-X configuration dialog can be seen where the input and
output devices is actually the ADX-ddsPIO board recognized as such.

## Quad

This is the prototype of the digital quadrature frequency synth (I/Q) clock

It's just used to evaluate the overall performance and yield unmodulated clock signals thru
ports GPIO14 (I) and GPIO15 (Q)

## si4732_rp2040

This is the prototype and test bench for a rp2040 based si4732 library

## testFS

This is the prototype and test bench for a configuration filesystem (FAT) to support
a configuration file (CONFIG.TXT) using the board as a USB MSC (aka pen drive).

## Others

There are other implementations which aren't functional by itself but only part of 
prototype and experimentation efforts on specific aspects.

* testUSB Algorithm for frequency measurement over the USB audio channcel.
* QP-7C_rp2040_cat Full implementation of USB Serial and Audio.

```
Unless otherwise specified do not expect to flash these projects on a raspberry pi pico 
and obtain any functionality
```

## DCO for Raspberry Pi Pico 

(Excerpts from the original **package pico-hf-oscillator** by Roman Piksaykin (R2BDY)
https://www.qrz.com/db/R2BDY

The *pico-hf-oscillator* library for Raspberry Pi Pico includes the headers and source code and all 
necessary build files to build a custom application which turns pico into precise PLL digital
frequency oscillator of the whole of HF radio spectrum (1 Hz to 32.333 MHz) with millihertz resolution.

## Precise frequency resolution

The library provides about 23 milli-Hz frequency resolution. This resolution is limited by 24-bit register which is used in algorithm.
A workingWSPR beacon which has been built on the base of this project proves that the quality of generated signal is sufficient to
such precise (~1.46 Hz step) frequency manipulation digital modes.

The upper freq. limit is ~32.333 MHz and it is achieved only using Pico overclocking to 270MHz.

mfsk-spectra

Here is an example of narrowband FSK (9.4 MHz carrier, 5 Hz step, 20 Hz range in total).

## Phased locked loop in C

The DCO uses phase locked loop principle programmed in C.

## *NO* additional hardware

The DCO provides the output signal on the GPIO pin. However if you want to
transmit the signal, you should calculate and provide a lowpass filter of
appropriate frequency. Please also figure out whether you possess rights
to emit radio frequency energy on desired frequency.

## GPS reference frequency correction (optional) since v.0.9

GPS reference frequency correction option provides an absolute frequency error within about ~1Hz in long term.
pico-hf-oscillator

## Dual-core

The DCO uses extensively the secodary core of the pico. The first one is for
your ideas how to modulate the DCO to obtain a desired signal.
The DCO does *NOT* use any floating point operations - all time-critical 
instructions run in 1 CPU cycle.

## Radio transmitters

Owing to the meager frequency step, it is possible to use 3, 5, or 7th harmonics 
of generated frequency. The practical resolution will be quite the same - far
below 1 Hz. Such solution completely cover all HF and VHF band up to ~233 MHz.

## Feedback to Roman

Roman will appreciate any thoughts or comments on that matter.

Roman Piksaykin, amateur callsign R2BDY
https://www.qrz.com/db/R2BDY

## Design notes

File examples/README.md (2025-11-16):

# ADX-rp2040-DDS Examples

This directory contains example programs demonstrating various features of the ADX-rp2040-DDS system.

## Available Examples

### 1. Simple Transmit (`simple_transmit.c`)

A basic example that demonstrates FT8 transmission.

**Features:**
- Initialize all subsystems
- Configure for 40m band
- Wait for USB audio
- Transmit FT8 messages periodically

**Usage:**
```bash
# Replace main.c with the example
cp examples/simple_transmit.c src/main.c

# Rebuild
cd build
make

# Flash to Pico
cp adx_rp2040_dds.uf2 /media/RPI-RP2/
```

### 2. Band Scanner (`band_scanner.c`)

Scans through amateur radio bands monitoring for activity.

**Features:**
- Cycle through all supported bands
- 30-second dwell time per band
- Display current band and frequency
- Receive mode only

**Usage:**
```bash
# Replace main.c with the example
cp examples/band_scanner.c src/main.c

# Rebuild
cd build
make

# Flash to Pico
cp adx_rp2040_dds.uf2 /media/RPI-RP2/
```

## Modifying Examples

### Changing Your Callsign

In `simple_transmit.c`, replace:
```c
ft8_start_transmission("LU7DID", "GF05", -10);
```

With your callsign and grid:
```c
ft8_start_transmission("YOUR_CALL", "YOUR_GRID", -10);
```

### Adjusting Scan Interval

In `band_scanner.c`, modify:
```c
const uint32_t scan_interval = 30000;  // milliseconds
```

### Changing Default Band

Both examples can be modified to use different default bands:
```c
adx_set_band(ADX_BAND_20M);  // Use 20m instead of 40m
```

Available bands:
- `ADX_BAND_80M` - 80 meters (3.573 MHz)
- `ADX_BAND_40M` - 40 meters (7.074 MHz)
- `ADX_BAND_30M` - 30 meters (10.136 MHz)
- `ADX_BAND_20M` - 20 meters (14.074 MHz)
- `ADX_BAND_17M` - 17 meters (18.100 MHz)
- `ADX_BAND_15M` - 15 meters (21.074 MHz)
- `ADX_BAND_10M` - 10 meters (28.074 MHz)

## Creating Your Own Examples

1. Start with one of the existing examples
2. Include necessary headers:
   ```c
   #include "config.h"
   #include "dds.h"
   #include "usb_audio.h"
   #include "adx_transceiver.h"
   #include "ft8_protocol.h"
   ```
3. Initialize all subsystems in your `main()`
4. Implement your custom logic
5. Process tasks in the main loop

## Testing Examples

### Required Hardware
- Raspberry Pi Pico or RP2040 board
- USB connection to computer
- (Optional) Oscilloscope for RF verification

### Monitoring Output
Connect to the USB serial port:
```bash
# Linux/macOS
screen /dev/ttyACM0 115200

# Windows - Use PuTTY or similar
```

### Verifying Operation
- Status LED should blink
- USB audio device should appear
- Serial output shows initialization messages
- GPIO 0 should show RF output (measure with scope)

## Notes

- These examples are for educational and testing purposes
- Ensure compliance with amateur radio regulations
- Use appropriate RF filtering and shielding
- Valid amateur radio license may be required
- Start with low power for initial testing

## Contributing

Have an interesting example? Submit a pull request! See [CONTRIBUTING.md](../CONTRIBUTING.md) for guidelines.

## Support

For questions or issues with examples:
1. Check the [main README](../README.md)
2. Review the [API documentation](../API.md)
3. Open an issue on GitHub

## License

All examples are provided under the same MIT License as the main project.

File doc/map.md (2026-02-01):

#define AUDIOSAMPLING    48000            // USB Audio sampling frequency (fixed)
#define PLL_SYS_MHZ        270            // RP2040 System Clock (MHz)  
#define PLL_SYS_MHZ_PLUS   290            // RP2040 System Clock (MHz) --OVERCLOCK--
#define GEN_FRQ_HZ    14074000L           // Generator Frequency (in Hz)
#define FT8_BASE_HZ       1000L           // FT8 base frequency (in Hz) <Not used>
#define FREQ_BFO        446400L           // BFO Frequency 

#define SLOT                  3
#define NBANDS                7
#define NMODES                4

#ifdef RDX
#define pin_ADC              26U          //pin for ADC (A0)
#else
#define pin_ADC              28U          //pin for ADC (A2)
#endif //RDX

#define pin_SW                3U          //pin for freq change switch (D10,input)

#define  CLK0                13           //RF output (transmitter)
#define  CLK1                12           //RF output (receiver)

#ifdef SUPERHET
#define CLK2                 14           //RF out Receiver IF (465 KHz)

#endif //SUPERHET

#ifdef QUAD
#define RFI                 14
#define RFQ                 15
#endif //QUAD

//#define I2C_PORT           i2c0
//#define SDA                  26           //I2C SDA (Data) bus
//#define SCL                  27           //I2C SCL (Clock) bus

#define RXSW                  2  //RXSW Switch (RX/TX control)
#define TXA                   9  //OE signal to driver

/*---
   LED
*/

#define TX                    3  //TX LED
#define FT8                   4  //FT8 LED
#define FT4                   5  //FT4 LED
#define JS8                   6  //JS8 LED
#define WSPR                  7  //WSPR LED

/*---
   Switches
*/    
#define TXSW                  8  //RX-TX Switch
#define UP                   10  //UP Switch
#define DOWN                 11  //DOWN Switch
#define BEACON               12  //BEACON Jumper

/*----
   Definitions for the Si4732 support
*/
#ifdef SI4732

#define I2C_PORT i2c0
#define SDA_PIN              16  //There must be an alternative as the rp2040Z does not exposse this
#define SCL_PIN              17  //nor this but alternatives in clear view are 26 & 27 which are also used by
#define RST_PIN               1  //pin 9 is available in rp2040Z and free in RDX but 1 is in conflict

#define SI4732_DEFAULT_REGION  "ar"
#define SI4732_DEFAULT_MODE   "ssb"
#define SI4732_DEFAULT_BAND   "20m"
#define SI4732_DEFAULT_VOLUME    50
#define SI4732_DEFAULT_MUTE       0

#define SI4732_LOAD_PATCH         1
int slot[4]   = {40,30,20,10};
int Band_slot = SLOT;                  //This is the default band Band1=1,Band2=2,Band3=3,Band4=4
int Band      =   20;                  //This is the default band
int mode      =    4;                  //Default mode is FT8

long unsigned int Bands[NBANDS][NMODES] = {
                                          { 3568600, 3578000, 3575000, 3573000},
                                          { 7038600, 7078000, 7047500, 7074000},
                                          {10138700,10130000,10140000,10136000},
                                          {14095600,14078000,14080000,14074000},
                                          {18104600,18104000,18104000,18100000},
                                          {21094600,21078000,21140000,21074000},
                                          {28124600,28078000,28180000,28074000}};

blinkslow
blinkmed
blinkfast

boardled

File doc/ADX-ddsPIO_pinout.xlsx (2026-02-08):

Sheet: rp2040 PinOut
Pin | Label | ADX-ddsPIO | rp2040Z | RDX | Purpose
1 | GPIO0 | Not Used | SDA | not used
2 | GPIO1 | RST | SCL | RST
3 | GND
4 | GPIO2 | RXSW | RXSW | RXSW | RX Enable
5 | GPIO3 | TX LED | TX LED | TX LED | TX Led On
6 | GPIO4 | FT8 LED | FT8 LED | FT8 LED | FT8 Led On
7 | GPIO5 | FT4 LED | FT4 LED | FT4 LED | FT4 Led On
8 | GND
9 | GPIO6 | JS8LED | JS8LED | JS8LED | JS8 LED On
10 | GPIO7 | WSPR LED | WSPR LED | WSPR LED | WSPR LED on
11 | GPIO8 | TXSW | TXSW | TXSW | TXSW Switch
12 | GPIO9 | RXA | RST | RXA | Driver Enable
13 | GND
14 | GPIO10 | UP SW | UP SW | UP SW | UP Button
15 | GPIO11 | DOWN SW | DOWN SW | DOWN SW | DOWN Button
16 | GPIO12 | RFLO | RFLO | RFLO | RX Local Oscillator
17 | GPIO13 | RFOUT | RFOUT | RFOUT | RF Signal Out (TX)
18 | GND
19 | GPIO14 | RFIF/RFQ | RFIF/RFQ | RFIF/RFQ | RF RX IF || RF(I)
20 | GPIO15 | RF(Q) | RF(Q) | RF(Q) | RF(Q)
21 | GPIO16 | SDA |  | SDA
22 | GPIO17 | SCL |  | SCL
23 | GND
24 | GPIO18 | not used |  | not used
25 | GPIO19 | not used |  | not used
26 | GPIO20 | not used |  | not used
27 | GPIO21 | not used |  | not used
28 | GND
29 | GPIO22 | not used |  | not used
30 | RUN | not used |  | not used
31 | GPIO26/ADC0 | RXA | RXA | RXA | Receiver audio
32 | GPIO27/ADC1 | not used | not used | not used | not used
33 | (A)GND | (A) GND |  |  | Analog Ground
34 | GPIO28/ADC2 | not used | not used | not used | not used
35 | ADC_VREF
36 | 3V3 | 3V3 (out) |  | 3V3 (out) | 3V3 (out)
37 | 3V3_EN | 3V3 (in)
38 | GND
39 | VSYS | VSYS
40 | VBUS | VBUS (+5 Vcc) in

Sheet: Hoja1
0 | 0.000000
1 | 6.250000
2 | 12.500000
3 | 18.750000
4 | 25.000000
5 | 31.250000
6 | 37.500000
7 | 43.750000

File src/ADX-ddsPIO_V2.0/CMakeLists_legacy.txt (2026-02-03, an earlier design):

# == DO NOT EDIT THE FOLLOWING LINES for the Raspberry Pi Pico VS Code Extension to work ==
if(WIN32)
    set(USERHOME $ENV{USERPROFILE})
else()
    set(USERHOME $ENV{HOME})
endif()
set(sdkVersion 2.2.0)
set(toolchainVersion 14_2_Rel1)
set(picotoolVersion 2.2.0-a4)
set(picoVscode ${USERHOME}/.pico-sdk/cmake/pico-vscode.cmake)
if (EXISTS ${picoVscode})
    include(${picoVscode})
endif()
# ====================================================================================
# Default FAMILY si no se pasó por -D
if(NOT DEFINED FAMILY)
  set(FAMILY "rp2040" CACHE STRING "TinyUSB family" FORCE)
endif()

# Default PICO_SDK_PATH si no se pasó por -D ni por env
if(NOT DEFINED PICO_SDK_PATH)
  if(DEFINED ENV{PICO_SDK_PATH})
    set(PICO_SDK_PATH "$ENV{PICO_SDK_PATH}" CACHE PATH "Path to Pico SDK")
  else()
    set(PICO_SDK_PATH "/Users/PCOLLA/Documents/GitHub/pico/pico-sdk" CACHE PATH "Path to Pico SDK")
  endif()
endif()

# ============================================================================
# Si no viene definido desde afuera, usar el SDK "de la empresa" (tu ruta)
if (NOT DEFINED PICO_SDK_PATH)
  set(PICO_SDK_PATH "/Users/PCOLLA/Documents/GitHub/pico/pico-sdk" CACHE PATH "Pico SDK Path")
endif()
# ============================================================================

set(CMAKE_C_COMPILER "/opt/homebrew/bin/arm-none-eabi-gcc")
set(CMAKE_CXX_COMPILER "/opt/homebrew/bin/arm-none-eabi-gcc")
option(PICOW "Support Raspberry Pi Pico Wireless" OFF)
set(CMAKE_EXPORT_COMPILE_COMMANDS ON)

cmake_minimum_required(VERSION 3.12)
include(/Users/PCOLLA/Documents/GitHub/pico/pico-sdk/lib/tinyusb/hw/bsp/family_support.cmake)
set(CMAKE_EXPORT_COMPILE_COMMANDS ON)

set(PROJECT ADX-ddsPIO)
set(TARGET ADX-ddsPIO)

set(PICO_BOARD pico)   # o pico_w, etc

#cmake_minimum_required(VERSION 3.12)
#pico_sdk_init()

#*---- Habilitado como recomendación para compilar picoW
#include($ENV{PICO_SDK_PATH}/external/pico_sdk_import.cmake)
#pico_sdk_init()
#*---- Habilitado para recomendación para compilar picoW

# Pull in PICO SDK (must be before project)

include(${PICO_SDK_PATH}/external/pico_sdk_import.cmake)
# NO LLAMAR pico_sdk_init() en este proyecto porque family_initialize_project() maneja la init

include(${PICO_SDK_PATH}/lib/tinyusb/hw/bsp/family_support.cmake)

project(${PROJECT} C CXX ASM)
#pico_sdk_init()

# gets PROJECT name for the example (e.g. <BOARD>-<DIR_NAME>)
family_get_project_name(${PROJECT} ${CMAKE_CURRENT_LIST_DIR})

#project(${PROJECT})

# Checks this example is valid for the family and initializes the project
family_initialize_project(${PROJECT} ${CMAKE_CURRENT_LIST_DIR})

add_executable(${PROJECT} src/main.c)

target_compile_options(${PROJECT} PRIVATE
    -Wall -Wextra
    -Werror
    -Wsign-conversion
    -Wconversion
)

# No tratar warnings de lwIP como errores (terceros)
if (TARGET pico_lwip)
    target_compile_options(pico_lwip INTERFACE -Wno-error -Wno-sign-conversion -Wno-conversion)
endif()
if (TARGET pico_lwip_nosys)
    target_compile_options(pico_lwip_nosys INTERFACE -Wno-error -Wno-sign-conversion -Wno-conversion)
endif()

# Example source
target_sources(${PROJECT} PUBLIC
        ${CMAKE_CURRENT_SOURCE_DIR}/src/main.c
        ${CMAKE_CURRENT_SOURCE_DIR}/src/usb_descriptors.c
        ${CMAKE_CURRENT_LIST_DIR}/src/piodco.c
        ${CMAKE_CURRENT_LIST_DIR}/src/si4732.c
        ${CMAKE_CURRENT_LIST_DIR}/src/usb_audio.c
        ${CMAKE_CURRENT_LIST_DIR}/src/lib/assert.c
        ${CMAKE_CURRENT_SOURCE_DIR}/src/usb_audio.c 
        ${CMAKE_CURRENT_SOURCE_DIR}/src/EEPROM.c 
        ${CMAKE_CURRENT_SOURCE_DIR}/src/quad.c 
        ${CMAKE_CURRENT_SOURCE_DIR}/src/si4732_patch_ssb.c

        )

target_include_directories(ADX-ddsPIO PUBLIC
        ${PICO_SDK_PATH}/lib/tinyusb/hw
        ${PICO_SDK_PATH}/lib/tinyusb/src
        ${CMAKE_CURRENT_LIST_DIR}/src
)

if (NOT EXISTS "${PICO_SDK_PATH}/lib/tinyusb/hw/bsp/rp2040/board.h")
  message(FATAL_ERROR "No se encuentra ${PICO_SDK_PATH}/lib/tinyusb/hw/bsp/rp2040/board.h")
endif()

if (PICOW)
target_link_libraries(${PROJECT} PUBLIC
        pico_stdlib
        tinyusb_device
        tinyusb_board
        pico_multicore
        hardware_pio
        hardware_adc
        hardware_i2c
        hardware_gpio
        hardware_rtc
        hardware_watchdog
        hardware_flash 
        hardware_sync
        #pico_cyw43_arch_lwip_threadsafe_background
        pico_cyw43_arch_lwip_poll
        )
endif() #PICOW

if (NOT PICOW)
target_link_libraries(${PROJECT} PUBLIC
        pico_stdlib
        tinyusb_device
        tinyusb_board
        pico_multicore
        hardware_pio
        hardware_adc
        hardware_rtc
        hardware_flash 
        hardware_sync
        hardware_i2c
        hardware_gpio
        hardware_watchdog
        hardware_clocks
        hardware_pll
        hardware_watchdog

        )
endif()  #!PICOW

#==============================[Específico para PicoW]=================================================
# Para que lwIP encuentre lwipopts.h cuando compila lwIP (no solo tu app)
if (PICOW)

if (TARGET pico_lwip)
    target_include_directories(pico_lwip INTERFACE ${CMAKE_CURRENT_LIST_DIR})
endif()

if (TARGET pico_lwip_nosys)
    target_include_directories(pico_lwip_nosys INTERFACE ${CMAKE_CURRENT_LIST_DIR})
endif()

if (TARGET pico_lwip_freertos)
    target_include_directories(pico_lwip_freertos INTERFACE ${CMAKE_CURRENT_LIST_DIR})
endif()
endif() #PICOW
#==============================[Específico para PicoW]=================================================

pico_add_extra_outputs(${PROJECT})

# Configure compilation flags and libraries for the example... see the corresponding function
# in hw/bsp/FAMILY/family.cmake for details.
family_configure_device_example(${PROJECT} noos)

pico_generate_pio_header(${PROJECT} ${CMAKE_CURRENT_LIST_DIR}/src/BFO.pio)
pico_generate_pio_header(${PROJECT} ${CMAKE_CURRENT_LIST_DIR}/src/dco2.pio)
pico_generate_pio_header(${PROJECT} ${CMAKE_CURRENT_LIST_DIR}/src/quad.pio)

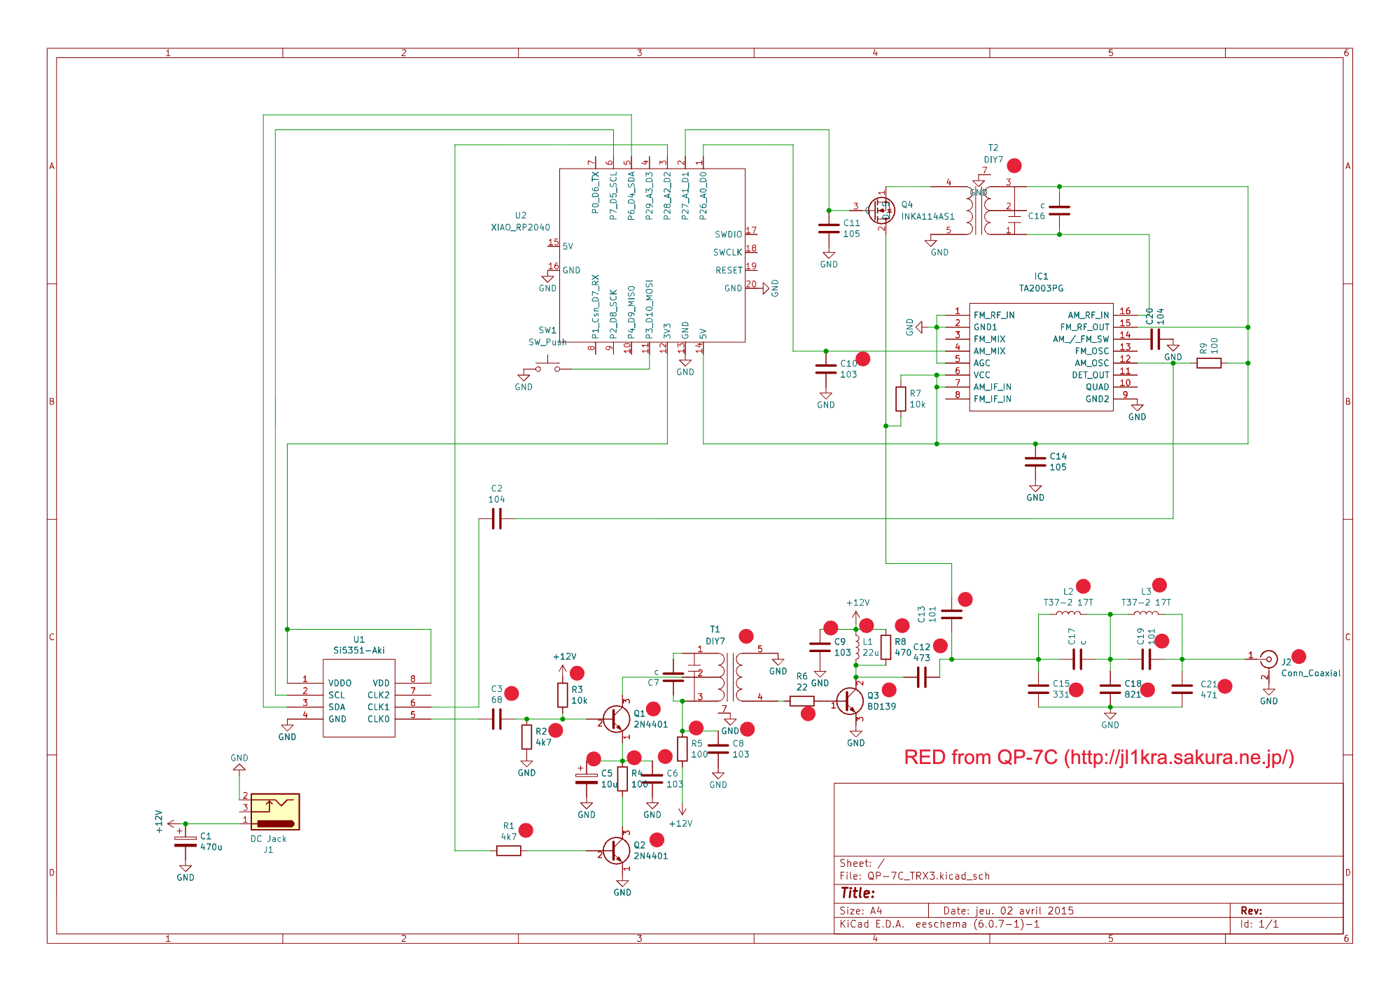
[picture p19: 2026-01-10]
doc/QP-7C_schematic.png

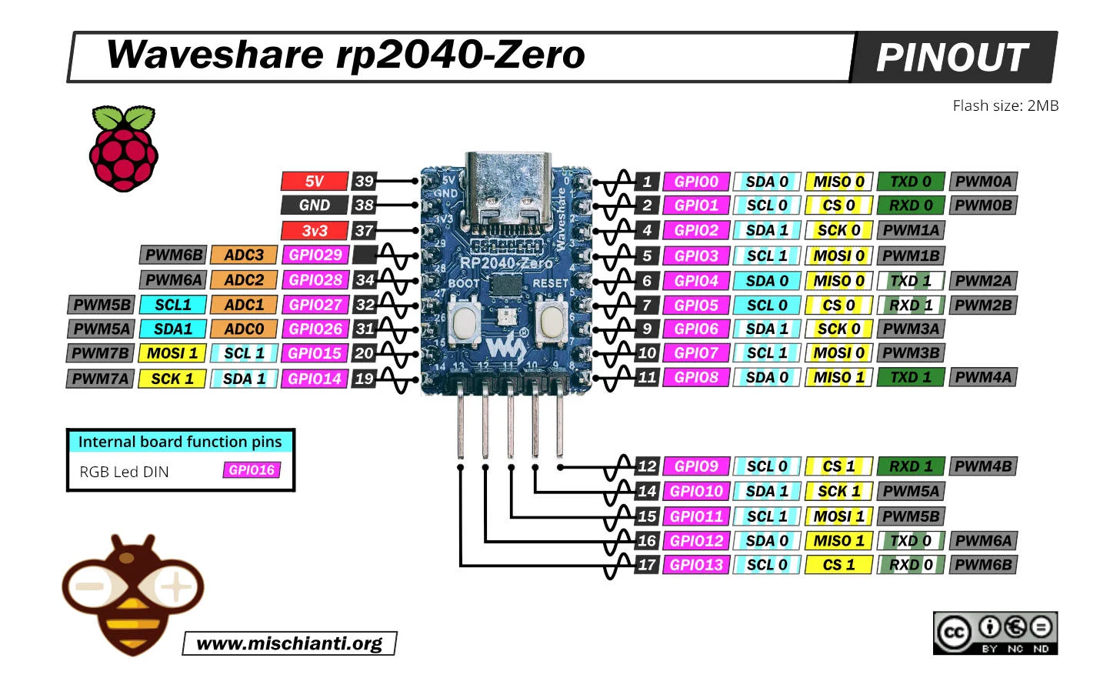
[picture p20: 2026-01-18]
doc/rp2040-zero-Raspberry-Pi-Pico-alternative-pinout.jpg.webp

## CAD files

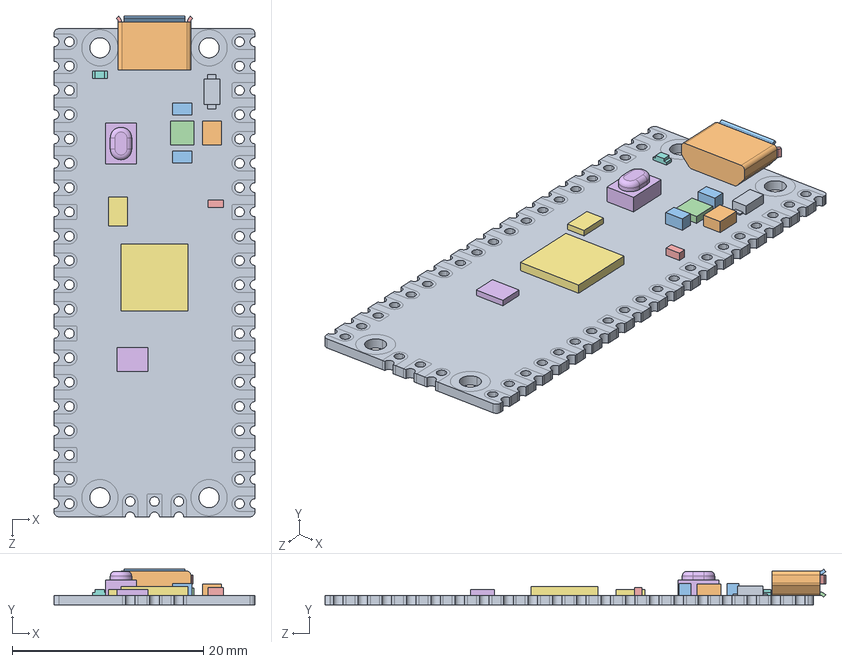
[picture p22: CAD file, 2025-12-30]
PCB/Raspberry-Pi-Pico-Symbol-and-Footprint-Library-Only/Pico-R3-step/Pico-R3.step
21.0 x 3.73 x 52.3 mm
PICO_REF_BOARD.STEP
PICO_REF_USB.STEP
PICO_REF_SWITCH.STEP
PICO_REF_MICROCONTROLLER.STEP
PICO_REF_LED.STEP
PICO_REF_ONSEMI.STEP
PICO_BOURNS.STEP
PICO_MURATA.STEP x 2
PICO_RICHTEK.STEP
PICO_DIODES.STEP
PICO_AEL.STEP
PICO_WINBOND.STEP

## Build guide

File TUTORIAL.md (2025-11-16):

# ADX-rp2040-DDS Tutorial

## Getting Started with ADX-rp2040-DDS

This tutorial will guide you through setting up and using your ADX-rp2040-DDS digital transceiver.

## Prerequisites

### Hardware
- Raspberry Pi Pico or RP2040-based board
- USB cable
- Computer with USB port
- (Optional) External RF amplifier and filters

### Software
- Pico SDK installed
- Build tools (CMake, ARM GCC)
- FT8 software (e.g., WSJT-X)
- Serial terminal (e.g., minicom, PuTTY)

## Step 1: Hardware Setup

### Basic Connections

```
┌─────────────────┐
│  Raspberry Pi   │
│     Pico        │
│                 │
│  USB ───────────┼──── Computer
│                 │
│  GPIO 0 ────────┼──── DDS Output (to RF circuit)
│  GPIO 16 ───────┼──── TX Control
│  GPIO 17 ───────┼──── RX Control
│  GPIO 25 ───────┼──── Status LED
│                 │
└─────────────────┘
```

### Power
Connect the Pico to your computer via USB. This provides both power and data connection.

## Step 2: Building the Firmware

### Install Pico SDK

```bash
# Clone Pico SDK
git clone https://github.com/raspberrypi/pico-sdk.git
cd pico-sdk
git submodule update --init
export PICO_SDK_PATH=$(pwd)
```

### Build ADX-rp2040-DDS

```bash
# Clone this repository
git clone https://github.com/lu7did/ADX-rp2040-DDS.git
cd ADX-rp2040-DDS

# Create build directory
mkdir build
cd build

# Configure and build
cmake ..
make -j4
```

### Output Files

After successful build:
- `adx_rp2040_dds.uf2` - Main firmware file

## Step 3: Flashing the Firmware

1. **Enter bootloader mode:**
   - Disconnect Pico from USB
   - Hold the BOOTSEL button
   - Connect to USB while holding BOOTSEL
   - Release BOOTSEL

2. **Flash firmware:**
   - The Pico appears as a USB drive (RPI-RP2)
   - Copy `adx_rp2040_dds.uf2` to this drive
   - The Pico will automatically reboot

3. **Verify:**
   - Status LED should blink once per second
   - USB serial port appears

## Step 4: Connecting to the Device

### Serial Terminal

Connect to the USB serial port:

```bash
# Linux/macOS
screen /dev/ttyACM0 115200

# Windows - use PuTTY
# Port: COMx, Baud: 115200
```

You should see:
```
ADX-rp2040-DDS Digital Transceiver Starting...
System Clock: 125000000 Hz
DDS initialized successfully
USB audio initialized successfully
ADX transceiver initialized successfully
FT8 protocol initialized successfully
ADX-rp2040-DDS is now running (experimental)
```

### USB Audio Device

The device appears as "ADX-rp2040-DDS" in your system's audio devices.

**Linux:**
```bash
aplay -l  # List playback devices
arecord -l  # List recording devices
```

**Windows:**
- Open Sound Settings
- Look for "ADX-rp2040-DDS"

**macOS:**
- Open System Preferences > Sound
- Look for "ADX-rp2040-DDS"

## Step 5: Using with WSJT-X

### Configure WSJT-X

1. **Open WSJT-X**

2. **File > Settings > Audio**
   - Input: Select "ADX-rp2040-DDS"
   - Output: Select "ADX-rp2040-DDS"
   - Sample Rate: 48000 Hz

3. **File > Settings > Radio**
   - Rig: None (USB audio only)
   - Mode: USB

4. **File > Settings > Frequencies**
   - Working frequency: 7.074 MHz (40m FT8)

### Operating

1. **Set your callsign and grid:**
   - File > Settings > General
   - Enter your callsign
   - Enter your grid locator

2. **Start monitoring:**
   - Click "Monitor" button
   - Watch for decoded signals

3. **Transmitting:**
   - Currently experimental
   - TX/RX controlled by software

## Step 6: Basic Testing

### Test DDS Output

You can verify the DDS output on GPIO 0 with an oscilloscope or frequency counter.

Expected output:
- Frequency: 7.074 MHz (40m band default)
- Waveform: PWM/Square wave

### Test USB Audio

Play a test tone through the device:

```bash
# Linux - generate test tone
speaker-test -D hw:ADXrp2040DDS -c 2 -r 48000
```

## Troubleshooting

### No USB Serial Port

- Check USB cable (must support data, not just power)
- Try different USB port
- Reflash firmware

### No Audio Device

- Wait 5-10 seconds after connecting
- Check USB connection
- Verify in device manager/system profiler

### LED Not Blinking

- Check power supply
- Verify firmware flashed correctly
- Try re-flashing

### No RF Output

- Check GPIO 0 with oscilloscope
- Verify band selection
- Check external RF circuit

## Advanced Configuration

### Change Default Band

Edit `src/adx_transceiver.c`:

```c
// Change this line:
adx_state.band = ADX_BAND_40M;  // Default to 40m

// To:
adx_state.band = ADX_BAND_20M;  // Default to 20m
```

Rebuild and reflash.

### Adjust TX Power

Edit `src/config.h`:

```c
#define TX_POWER_DEFAULT    50  // Change to desired %
```

### Custom Frequencies

Edit band frequency table in `src/adx_transceiver.c`:

```c
static const uint32_t band_frequencies[ADX_BAND_COUNT] = {
    3573000,   // 80m - customize these
    7074000,   // 40m
    // ...
};
```

## Safety and Legal

⚠️ **Important:**
- This generates RF signals
- Ensure proper filtering and shielding
- Use appropriate antenna
- Comply with local amateur radio regulations
- Valid amateur radio license may be required
- Start with low power for testing

## Next Steps

1. Test with different bands
2. Experiment with FT8 communications
3. Add external RF amplifier
4. Design and build proper RF filters
5. Create custom PCB

## Support

- GitHub Issues: Report bugs and request features
- Documentation: See API.md for programming reference
- Contributing: See CONTRIBUTING.md to help develop

## Resources

- [WSJT-X Software](https://physics.princeton.edu/pulsar/k1jt/wsjtx.html)
- [FT8 Operating Guide](https://physics.princeton.edu/pulsar/k1jt/FT8_Operating_Tips.pdf)
- [RP2040 Datasheet](https://datasheets.raspberrypi.com/rp2040/rp2040-datasheet.pdf)
- [Pico SDK Documentation](https://raspberrypi.github.io/pico-sdk-doxygen/)

## Enjoy!

Have fun experimenting with your ADX-rp2040-DDS digital transceiver! 73 de LU7DID

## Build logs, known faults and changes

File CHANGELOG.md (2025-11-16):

# Changelog

All notable changes to the ADX-rp2040-DDS project will be documented in this file.

The format is based on [Keep a Changelog](https://keepachangelog.com/en/1.0.0/),
and this project adheres to [Semantic Versioning](https://semver.org/spec/v2.0.0.html).

## [Unreleased]

### Planned
- Complete FT8 encoding/decoding implementation
- Full USB audio device functionality
- Hardware validation and testing
- Performance optimization
- Additional digital modes (PSK31, RTTY)
- Web-based configuration interface

## [0.1.0] - 2025-11-16

### Added
- Initial project structure and build system
- CMake configuration for RP2040/Pico SDK
- DDS (Direct Digital Synthesis) module
  - PIO/PWM-based signal generation
  - Frequency control (1-30 MHz)
  - No external Si5351 required
- USB Audio Device module
  - TinyUSB integration
  - 48 kHz stereo audio
  - Digital sound card interface
- ADX Transceiver module
  - TX/RX mode switching
  - Multi-band support (80m, 40m, 30m, 20m, 17m, 15m, 10m)
  - Power control (0-100%)
- FT8 Protocol module
  - Basic FT8 framework
  - Message structure
  - Transmission control
- Configuration system
  - Centralized config.h
  - Hardware pin assignments
  - Audio and DDS parameters
- Documentation
  - Comprehensive README.md
  - BUILD.md with build instructions
  - HARDWARE.md with hardware design
  - API.md with complete API reference
  - CONTRIBUTING.md for contributors
  - TUTORIAL.md for getting started
- USB descriptors for device identification
- TinyUSB configuration
- .gitignore for build artifacts

### Technical Details
- Target: Raspberry Pi RP2040 (Cortex-M0+ @ 125MHz)
- Language: C11
- Build System: CMake 3.13+
- USB Stack: TinyUSB
- Audio: 48kHz, 16-bit, stereo
- DDS: Direct synthesis via PIO/PWM

### Notes
- This is an experimental release
- Hardware testing pending
- FT8 encoding/decoding are placeholders
- Full USB audio not yet implemented

## Version History

### Version Numbering
- Major: Significant feature additions or API changes
- Minor: New features, backward compatible
- Patch: Bug fixes and minor improvements

### Release Tags
- v0.1.0 - Initial experimental release

## Future Roadmap

### v0.2.0 (Planned)
- Complete FT8 implementation
- Working USB audio device
- Hardware validation

### v0.3.0 (Planned)
- Additional digital modes
- Improved DDS performance
- Configuration interface

### v1.0.0 (Future)
- Production-ready release
- Full feature set
- Tested and stable

## Contributing

See [CONTRIBUTING.md](CONTRIBUTING.md) for how to contribute to this project.

## Links

- [GitHub Repository](https://github.com/lu7did/ADX-rp2040-DDS)
- [Issue Tracker](https://github.com/lu7did/ADX-rp2040-DDS/issues)
- [Releases](https://github.com/lu7did/ADX-rp2040-DDS/releases)

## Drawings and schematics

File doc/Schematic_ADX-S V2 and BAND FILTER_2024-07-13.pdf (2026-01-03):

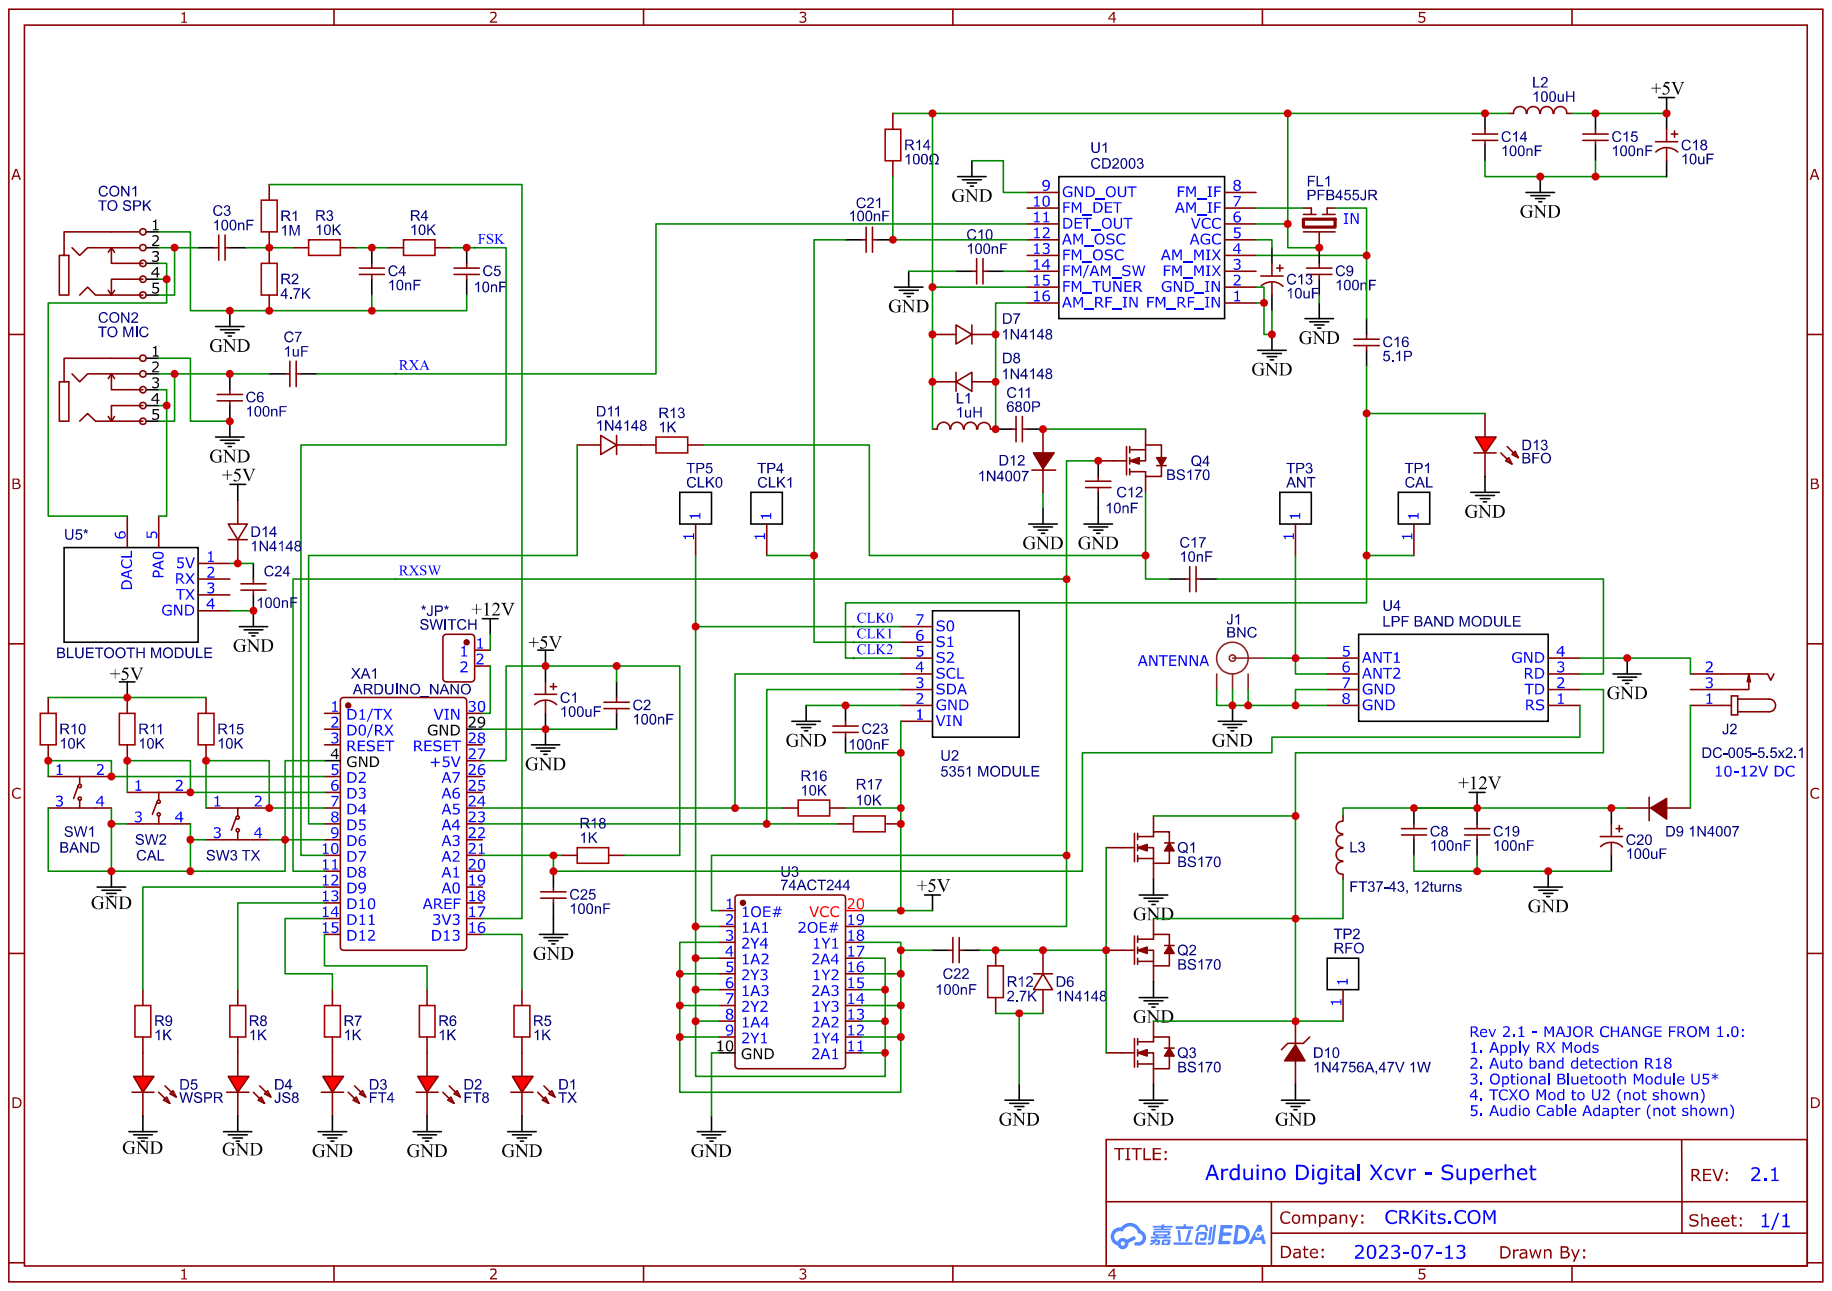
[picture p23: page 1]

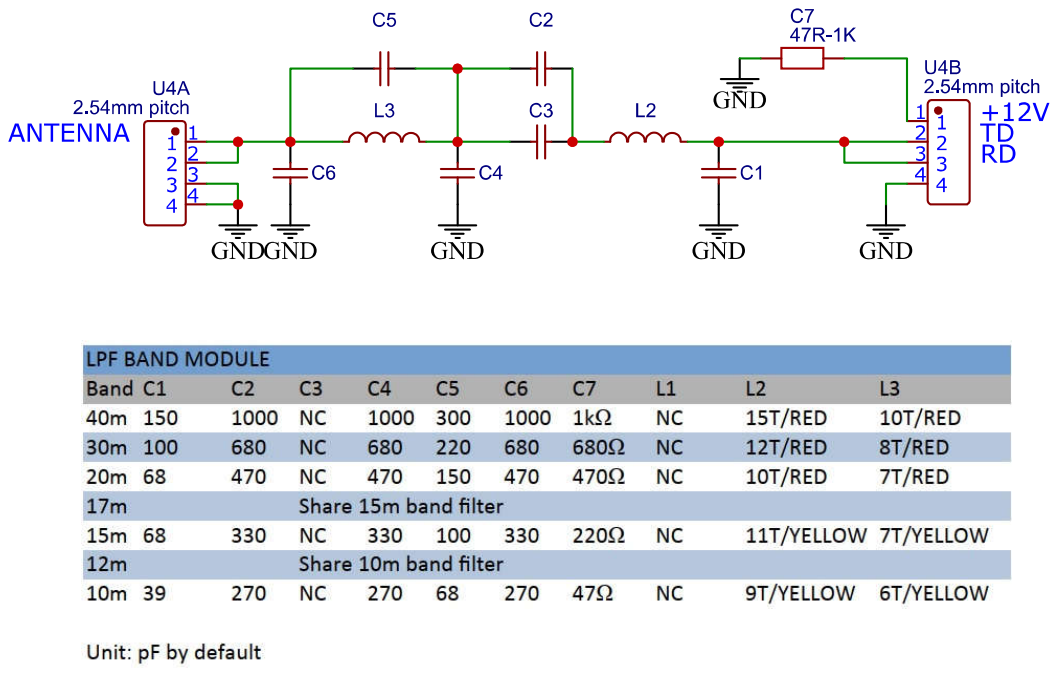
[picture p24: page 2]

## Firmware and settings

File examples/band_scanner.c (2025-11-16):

/**
 * Band Scanner Example for ADX-rp2040-DDS
 * 
 * This example demonstrates scanning through amateur radio bands
 * and monitoring FT8 activity
 * 
 * Usage:
 * 1. Replace main() in src/main.c with this code
 * 2. Rebuild the project
 * 3. Flash to the Pico
 */

#include <stdio.h>
#include "pico/stdlib.h"
#include "config.h"
#include "dds.h"
#include "usb_audio.h"
#include "adx_transceiver.h"
#include "ft8_protocol.h"

// Band names for display
static const char* band_names[] = {
    "80m", "40m", "30m", "20m", "17m", "15m", "10m"
};

int main() {
    // Initialize stdio
    stdio_init_all();
    
    // Initialize status LED
    gpio_init(PIN_STATUS_LED);
    gpio_set_dir(PIN_STATUS_LED, GPIO_OUT);
    
    printf("Band Scanner Example\n");
    printf("====================\n\n");
    
    // Initialize all subsystems
    dds_init();
    usb_audio_init();
    adx_transceiver_init();
    ft8_protocol_init();
    
    // Start in RX mode
    adx_set_mode(ADX_MODE_RX);
    
    // Wait for USB audio
    printf("Waiting for USB audio...\n");
    while (!usb_audio_is_ready()) {
        usb_audio_task();
        sleep_ms(100);
    }
    printf("USB audio ready!\n\n");
    
    // Scanning parameters
    adx_band_t current_band = ADX_BAND_40M;
    uint32_t time_on_band = 0;
    const uint32_t scan_interval = 30000;  // 30 seconds per band
    
    printf("Starting band scan...\n");
    printf("Scan interval: %lu seconds per band\n\n", scan_interval / 1000);
    
    while (true) {
        // LED blink pattern
        gpio_put(PIN_STATUS_LED, 1);
        sleep_ms(50);
        gpio_put(PIN_STATUS_LED, 0);
        
        // Process tasks
        adx_transceiver_task();
        usb_audio_task();
        ft8_protocol_task();
        
        // Check if it's time to change bands
        if (time_on_band >= scan_interval) {
            // Move to next band
            current_band = (current_band + 1) % ADX_BAND_COUNT;
            adx_set_band(current_band);
            
            printf("Scanning: %s (%lu Hz)\n", 
                   band_names[current_band],
                   dds_get_frequency());
            
            time_on_band = 0;
        }
        
        time_on_band += 100;
        sleep_ms(100);
    }
    
    return 0;
}

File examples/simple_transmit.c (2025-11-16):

/**
 * Simple Transmit Example for ADX-rp2040-DDS
 * 
 * This example demonstrates basic FT8 transmission
 * 
 * Usage:
 * 1. Replace main() in src/main.c with this code
 * 2. Rebuild the project
 * 3. Flash to the Pico
 */

#include <stdio.h>
#include "pico/stdlib.h"
#include "config.h"
#include "dds.h"
#include "usb_audio.h"
#include "adx_transceiver.h"
#include "ft8_protocol.h"

int main() {
    // Initialize stdio
    stdio_init_all();
    
    // Initialize status LED
    gpio_init(PIN_STATUS_LED);
    gpio_set_dir(PIN_STATUS_LED, GPIO_OUT);
    
    printf("Simple Transmit Example\n");
    
    // Initialize all subsystems
    dds_init();
    usb_audio_init();
    adx_transceiver_init();
    ft8_protocol_init();
    
    // Configure for 40m band (7.074 MHz)
    adx_set_band(ADX_BAND_40M);
    
    // Set transmit power to 50%
    adx_set_power(50);
    
    printf("Configuration:\n");
    printf("  Band: 40m (7.074 MHz)\n");
    printf("  Power: 50%%\n");
    printf("  Mode: FT8\n");
    
    // Wait for USB audio to be ready
    printf("Waiting for USB audio...\n");
    while (!usb_audio_is_ready()) {
        usb_audio_task();
        sleep_ms(100);
    }
    printf("USB audio ready!\n");
    
    // Transmit sequence
    uint32_t sequence = 0;
    
    while (true) {
        // Blink LED
        gpio_put(PIN_STATUS_LED, 1);
        sleep_ms(100);
        gpio_put(PIN_STATUS_LED, 0);
        
        // Process tasks
        adx_transceiver_task();
        usb_audio_task();
        ft8_protocol_task();
        
        // Transmit every 60 seconds (4 FT8 time slots)
        if (!ft8_is_transmitting() && (sequence % 600 == 0)) {
            printf("\n--- Starting FT8 transmission #%lu ---\n", sequence / 600 + 1);
            
            // Start transmission with your callsign and grid
            // Replace these with your actual callsign and grid
            ft8_start_transmission("LU7DID", "GF05", -10);
        }
        
        sequence++;
        sleep_ms(100);
    }
    
    return 0;
}

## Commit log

2026-01-03 Ignorar archivos .DS_Store de macOS
2026-02-04 usb: MSC mounts on macOS using preformatted FAT12 image
2026-02-08 ADX-ddsPIO V2.0 clean up
    [ADX-ddsPIO_pinout.xlsx]
